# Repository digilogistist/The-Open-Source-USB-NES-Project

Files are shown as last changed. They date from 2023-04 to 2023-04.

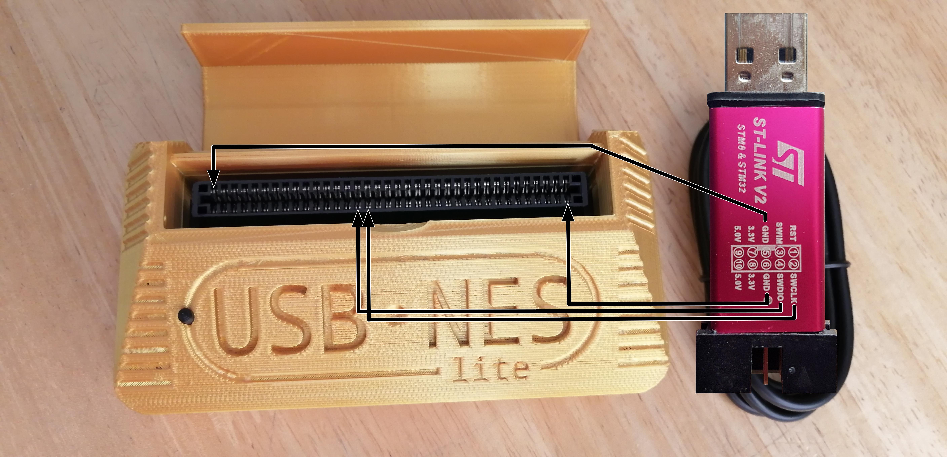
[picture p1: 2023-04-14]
USB-NES-SWD_pinout.jpg

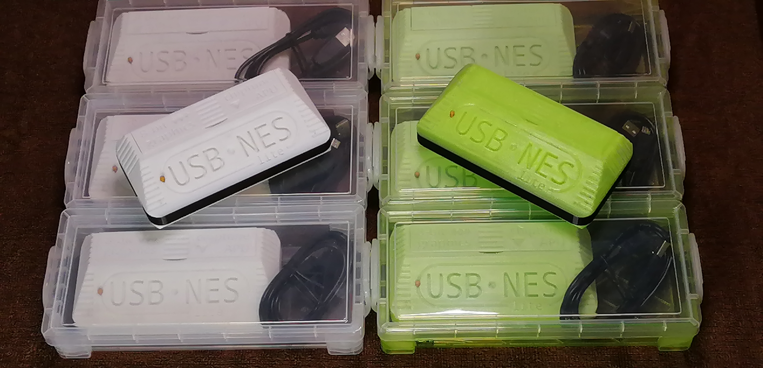
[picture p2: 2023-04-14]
gallery/IMG_20230210_211953.jpg

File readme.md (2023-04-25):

# USB-NES Lite Project Public Release

Brad Taylor  
BTTD Group  
04/05/2023  
https://usbnes.com  

### This is the complete USB-NES Lite 0.08/0.79 production unit engineering archive, containing:

- Source code
- Firmware binaries (composite and discrete)
- PCB engineering files (USB-NES, NES-BACKUP and new NES-FASTGFX)
- Serial wire debug wiring diagram
- Technical documentations
- Quick setup guide print-out
- DIY kit guide print-out (manufacturing instructions)
- Owner's manual PDF
- 3D case models
- Manufacturing BOMs and part source links
- Photo gallery

## Firmware Binaries

Inside the USB-NES is an STM32F103C8 microcontroller running at 72 MHz, which usually includes a very cozy 64 K Bytes of on-board flash memory.  Sometimes as a bonus though, the "Blue Pill" comes with double that amount of storage (and possibly even all the time).  While these differences are normally considered a toss-up on a few innocent chance purchases, the 128 KB flash types (aka incognito 'F103CB ones) are more commonly seen with marketplace Blue Pill system boards at slightly higher price points.

Nowadays, the Blue Pills are not as cheap, available, nor as powerful as newer mini system board offerings on the market, but the first generation blue pills with the through-hole mounted micro-USB port and low-profile reset push button switches are the absolute best types you can still get your hands on, if you're lucky.

Moreover, the main functional USB-NES firmware uses only the first 64 KB of flash, where as units with 128 KB would include a DEMO.NES graphics demonstration ROM that would fit in the bonus 64 KB of flash as additional superfluous brand marketing.  The firmware checks for the classic iNES signature where the DEMO.NES file is allocated on the flash to determine if the file should be created in the USB-NES file system.  Therefore, the DEMO.NES binary allocated there can technically be any defacto .NES image that can fit within the high 64 KB flash of a lucky 128 KB Blue Pill sample.  

|Micro Type  |Flash Location|Size  |Composite Binary Source |
|:---|---:|-----:|:---|
|STM32F103C8 |0x 0800 0000  | 64 KB|/USB-NES_Lite_0.08-0.79_64K.bin |
|STM32F103CB~|0x 0800 0000  |128 KB|/USB-NES_Lite_0.08-0.79_128K.bin|

~ may also be labelled as a "lucky" 'F103C8 model.  

|Flash section |Flash Location|Size |Discrete Binary Location |
|:---|---:|----:|:---|
|Boot Block @|0x 0800 0000  | 4 KB|/firmware/boot_block/boot_block.bin |
|Kernel ~$|0x 0800 1000  |28 KB|/firmware/kernel/Debug/kernel.bin |
|Application ^$|0x 0800 8000  |26 KB|/firmware/application/Debug/application.bin|
|SETTINGS.TXT %|0x 0800 E800  | 1 KB| |
|BCMTABLE.BIN  |0x 0800 EC00  | 1 KB|/firmware/BCMTABLE.BIN |
|OVERRIDE.BIN  |0x 0800 F000  | 4 KB|/firmware/OVERRIDE.BIN |
|DEMO.NES &|0x 0801 0000  |64 KB|/firmware/DEMO.BIN |

~ Uses lower 10 KB of system RAM  
^ Uses upper 10 KB of system RAM  
$ Compiled using Atollic TruStudio (see ./BUILD.BAT for console log)  
% This data is auto-generated by the application firmware  
& DEMO.NES is disabled in SETTINGS.TXT by default  
@ Assembled and output to binary using windy script /firmware/boot_block/BUILD.BAT  

### Flashing the discrete binaries to USB-NES
1. Acquire an ST-LINK Serial Wire Debug programming tool; they are cheap + easy to get.
2. Install the ST-LINK programming utility software.
3. Refer to the /USB-NES-SWD_pinout.jpg for connecting the ST-LINK to USB-NES via SWD.
4. Be sure the USB-NES has its USB port powered when connecting via SWD.
5. Hold in the reset button on USB-NES for a couple of seconds or so, while using the ST-LINK utility to connect to the STM32F103 micro via SWD interface.
6. Deactivate the readout protection on the STM32F103 by unchecking it in the option switches.  Please note this will completely erase the existing contents of the USB-NES firmware.  If the readout protection is not active, you should instead erase the entire contents of the chip by using the utility's Erase command.
7. Load the binary files into the ST-LINK utility~, and program them to the aforementioned corresponding locations in flash memory.  The five critical binaries to flash to USB-NES are the Boot Block, Kernel, Application, BCMTABLE.BIN, and OVERRIDE.BIN.  SETTINGS.TXT is auto-generated by the application, and DEMO.NES is entirely optional (for 128 KB units only).

~ Alternately, the ST-LINK utility command line interface may also be used to flash all five critical binaries automatically; please see /FLASHBALL.BAT for a windy example.

## Source Code

The Kernel and Application projects offered here are built with STM32cubeMX, using the USB FS and mass storage class middlewares provided by ST Microelectronics, which is copywritten code.  Therefore, their source code is provided here strictly under the "fair use" doctrine; no infringement is implied nor intended in its parallel inclusion with this public-domain USB-NES preservation project and related functional source code files.

This default USB layer uses almost all the flash space in the kernel, but probably can be optimized to use less.  Moreover, the STM32cubeMX does not allow the implementation of a USB composite device (such as MSC + HID) on this particular STM32 micro; this is why USB-NES Lite never got NES gamepad socket add-ons over its trial run.  Many on-and-off attempts were made to hack together the two separate STM32 USB functions with no success; it is not clear to me at the time of this writing if the STM32F103C8 has enough flash or RAM resources to employ a USB MSC + HID composite device within the confines of the kernel binary.

The main functional USB-NES source code provided here is located as follows:

|Source type|Language  |Size  |Location |
|:---|:---|-----:|:---|
|Boot Block |ARM M3 ASM| 13745|/firmware/boot_block/boot_block.s |
|Kernel |C | 25177|/firmware/kernel/Src/usbd_storage_if.c|
|Application|C |120352|/firmware/application/Src/main.c |

## PCB Files

Both USB-NES-02 and NES-BACKUP-02 are electrically identical products, and differ only with the Blue Pill/USB port orientation (side vs. back) to their respective PCBs.

The NES-BACKUP-02 PCB predates USB-NES-02, and does not have a nice shell design like for USB-NES Lite.  Note the only feature of this PCB is the 6-pin header that connects to the NES cartridge CIC pins, for easy AVR CIclone boardset programming.  Only 11 NES-BACKUP-01 units are currently known to exist.  Note there is no corner mounting holes, nor is there a footprint for the necessary electrolytic capacitor in this design, which are bugs that need addressing.  The -02 revision fixes a footprint pinout bug present on the -01 models, involving the orientation of the power MOSFET component.

USB-NES-02 is a better follow-up PCB to the aforementioned design, that adds in an experimental mini phone plug for theoretical expansion audio access, and leaves room in the front for further possible expansions like NES gamepad ports and such.  At least 100 USB-NES-01 PCB assemblies are known to exist, and many of these have been assembled into complete USB-NES Lite consumer units.  Note there is no footprint for the necessary electrolytic capacitor in this design, but it is possible to piggy-back solder it onto existing points on the PCB assembly (see /cap_add/ for pix).  A 1.6 mm PCB thickness is strongly recommended for manufacturing USB-NES-02.  All USB-NES firmware binaries mentioned in this document are intended for USB-NES-02.

USB-NES-04 is an enhanced version of the previous design that adds four controller ports to the USB-NES.  There is no firmware that exists yet to take advantage of the enhancements in this hardware design.  Moreover, no PCBs nor related shell designs have yet been manufactured for this either.  More info here:  
https://youtu.be/dRpi10Yrjks

NES-FASTGFX-01 is a completely original concept NES cart mapper (1.2 mm thick) PCB design made for new NES game development.  A complete manufacturing BOM + working (as of 04-13-2023) parts source list for NES-FASTGFX-01 can be found in "/PCB (NES-FASTGFX-01)/BOM-FASTGFX.ods"

### NES-FASTGFX-01 Specs
- 512 K byte PRG flash (SST39SF040)
- 32 K byte PRG-RAM
- 512 K byte CHR-RAM
- 32768 playfield tiles (@ PPU $0000-$0FFF)
- 4 PPU mirroring modes
- 16-bit VBLANK time stamp counter
- 128 sprite banks (@ PPU $1000-$1FFF)
- HI name table located in first 2 KB of CHR-RAM
- 4-CPU clock cycle CHR-RAM byte filling @ PPU $2000-$3EFF~
- ATMEL ATtiny13A CIClone twin footprint (through-hole & SMT)

~ CPU writes to PPU data I/O register $2xx7/$3xx7, will write the encoded 8-bit xx value to the CHR-RAM in one single STA/STX/STY abs. 6502 instruction.  In this case, writes to PPU $2000-$2FFF memory will fill the HI name tables with the xx value (and internal 2 KB LO NT as per usual CPU data), while writes to PPU $3000-$3EFF will write xx to the selected CHR-RAM sprite bank (meanwhile disabling the LO NT).  The CHR-RAM may also be disabled during name table fills, when updating only the LO NT is desired.   Moreover, the CHR-RAM may also be bi-directionally accessed via the traditional CPU $2007 data I/O port @ PPU $1000-$1FFF memory, swapping in the selected 4 KB sprite bank there as well.  PPU bank $0000-$0FFF is only used for playfield rendering; it can just be ignored otherwise.

The most notable feature of this mapper is the expansion of the original 8-bit name table tile codes to 15-bits; this is made possible by using a private graphics data bus in the cartridge for handling the NT HI business during a NT fetch phase.  Moreover, the NT fetch phase is identified as a read cycle from PPU $2000-$3FFF that follows a read from PPU $0000-$1FFF; this corresponds to how the PPU fetches CHR memory during on-screen playfield rendering.  The NT HI byte is then fetched from the first 2KB of CHR-RAM (using the identical mirroring scheme the NES internal 2K VRAM is configured for), and is stored in a register.  The register is then used as the basis for the 4KB bank selection for pattern graphics access @ PPU $0000-$0FFF, which is where the PPU should be normally configured to allocate the 4KB playfield graphics bank.

The VBLANK time stamp counter is reset from any reads from the PPU, so once screen rendering is done, this counter will start to count up every CPU clock.  Consequently, the 16-bit value read here can indicate how far the PPU is in VBLANK or the frame render period, relative to the CPU NMI event (or thereabouts).  If your VBLANK code runs past the 20-scanline (NTSC) limit, the time stamp counter can be used as the basis for forming the correct PPU scroll programming values, based on how many scanlines the render has advanced into the visible frame.  Reading the LO byte of the time stamp count register latches the next LO and HI 8-bit time stamp count samples to be read back.  Therefore, it is possible to only just read the LO TSC register when measuring CPU clock counts of less than 256 clocks.

When using FASTGFX for NES game development, writing to PPU memory is up to 50% faster, and VBLANK code time may be extended dynamically past the on-screen cutoff point, all while having access to a serious amount of graphical tiles for use with both backgrounds and sprites.

### Flash Cart Story
NES-FASTGFX-01 is the answer to a previous programmable NES cart production attempt I made back in 2018: "NES-RED-PILL-02". This older design was more complicated due to the presence of both CHR-RAM and CHR-flash, where the PPU architecture is split into separate sections for sprites (RAM) and playfield tiles (flash/RAM).  The idea was to have 512 KB of CHR-flash for background tiles, and 32 KB CHR-RAM for sprites + BG, but the hardware required to implement the 16-bit background tile index code extensions ended up making programming the CHR-flash chip a complex nightmare.

This was also my first attempt implementing 5-volt flash chips into a new NES cart design.  One critical detail about using flash chips for PRG memory versus SRAM is the requirement of an inverted read/write line for the /OE input on the chip, which would normally just be tied to ground for a typical SRAM implementation.

My long-term plan was to develop game software for the NES using these cart boards, while using NES-BACKUP/USB-NES as the main flashing/programming tool, providing an easy-to-use drag + drop user interface.  These boards have a lot of SMD parts on them, so I got ten of them manufactured and populated professionally, which also made this cart production really expensive.

Subsequently however, once I had built NES-BACKUP and started testing out the NES-RED-PILL boards, I found out I made some fatal design mistakes on the boards.  Most notably, I discovered that both CHR and PRG flash chips could not be programmed efficiently or even at all, without reworking the boards and adding another chip!  After eventually reworking one board, I did manage to get the PRG + CHR flashing to work with USB-NES, but when programming the CHR-flash there was always 4KB in the last bank on the chip that would not flash correctly.  I couldn't figure out what the source of the CHR-flash corruption was, and lost my nerve.  From there on (late 2019), I focused on developing the USB-NES firmware, since I was at a loss with my game boards.

Then three years later, I reworked a second NES-RED-PILL board to discover that the CHR-flash on the first board was actually fried.  Apparently, all the initial testing I was doing on these boards before reworking them was enough to cause the CHR-flash chip on one board to partially self-destruct, and cause it to always fail a full flash memory programming test.  But now, the second reworked board was flashing perfectly using USB-NES!  So now I know what I did wrong, and how to do it right this time.

I took everything I learned from that first costly and disappointing NES-RED-PILL production disaster, trimmed the fat and tweaked the ideas, and made NES-FASTGFX: a state-of-the-art, open-source, graphics expansion NES development cartridge boardset PCB design, that adds powerful extensions to the NES architecture with a simplified programming environment, using a handful of easy-to-source boardset parts.

USB-NES support for NES-FASTGFX boardset development with full drag + drop PRG-flashing is speculated down the road, using existing methods in the USB-NES source code that have been 100% tested and confirmed working on reworked NES-RED-PILL-02 flash boards.  More info on the NES-RED-PILL can be seen here:

https://youtu.be/C34mVn180Tk  
https://youtu.be/JX10NZo6VX4

## USB-NES Lite BOM

/BOM-final_USB-NES_Lite_2021.ods

This bill of materials includes everything to make a production USB-NES Lite system, with a working (as of 04-13-2023) part source list.

The 3D models are typically printed via 1.75/0.4 mm filament/nozzle 3D printer with 5% infill, 0.2 mm layers, and 1.2 mm top/bottom thickness.

The PCB files were made with Kicad.

Do not assemble before reading the manufacturing instructions.

## Manufacturing Instructions

The step-by-step assembly guide for building USB-NES Lite is contained in:  
/USB-NES DIY KIT (p.1).pdf  
/USB-NES DIY KIT (p.2).pdf  
https://usbnes.com/usb-nes-lite-diy-kit/  

The companion video can be found here (doesn't cover adding the capacitor):  
https://youtu.be/VL_1Z1ONgns  

The capacitor install guide here:  
/cap_add/  
https://usbnes.com/power-system-upgrade/

## Thank-Yous

All the USB-NES Lite project supporters  
The entire NES emulation dev scene  
Generational Gamer  
Paul Belanger  
Thor Robinson  
Troy Denton  
Henry Hoy  
Wolf  
Loopy  
Disch  
Dwedit  
Blarrg  
nocash  
Tepples  
Kevtris  
Bootgod  
Bregalad  
Bananmos  
Tokumaru  
Lidnariq  
Ulfalizer  
Rainwarrior  
infiniteneslives  
beannaich  
Quietust  
Memblers  
jeffqchen  
NEScartDB  
NESDEV wiki  
Eugene's blog  
ST Microelectronics  
Nintendo of America, Inc. (and NCL of Japan, too)  
And of course, the reader  

## License

Copywritten works, such as technical manuals and source code included in this repository are for educational and preservational "fair use" purposes only.  No copyright infringement is implied, solicited nor intended with the inclusion of these copywritten works for the Open-Source USB-NES Project.

The rest of the work in this archive, including any BTTD Group or Brad Taylor properties, is licensed under a Creative Commons Attribution-ShareAlike 4.0 International License.

http://creativecommons.org/licenses/by-sa/4.0/

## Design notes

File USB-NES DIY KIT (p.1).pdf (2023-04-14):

USB-NES Do-It-Yourself Kit Assembly Guide
Brad Taylor
OCT 17 2022

Please see our DIY companion video and documentation on our website for more info: https://usbnes.com/usb-nes-lite-diy-kit/

1. What you’ll need:
* USB-NES Lite parts kit (thank-you for your purchase)
* USB-NES 3D print model
* Filament 3D printer
* Fine-tipped soldering iron + station + solder
* Solder wick (optional; for removing solder bridges and excess solder) * “3rd Hand” PCB holder
* Magnifying glass (optional; for inspecting solder joints)
* Flat-tipped or electronics’ tweezers
* Lineman’s pliers / needle-nose or similar type
* #1 Phillips screwdriver
* Utility knife
* Flush cutters (optional)
* Intermittent soldering skills
* Patience and persistence (estimated 1 hour assembly time)
2. Open and Examine the USB-NES assembly kit:
1x Protective jewel case
1x STM32 barebones system “blue pill” board (preprogrammed with current USB-NES firmware) 1x 40-pin single-inline header
1x 4-pin single-inline header
1x 6-pin dual-inline header
1x thin jumper wire
1x Printed circuit board “USB-NES-01” 1x 72-pin NES cart connector
1x surface-mount 10k-ohm resistor
1x surface-mount P-channel power mosfet 1x surface-mount level shifter
1x 3ft. Micro-USB cord
4x #4-40 x 1″ machine screws
2x #4-40 x 11/16″ machine screws
1x 560 uF electrolytic capacitor
3. Prep the pin headers:
* Break the 40-pin header into 2 equal sections of 20 pins.
* Use pliers to straighten the 4-pin header
* Use pliers again to slide the 4-pin header spacer down to be equal to that of the other 20 pin ones. * Remove and discard the 2 yellow jumpers from the 6-pin header.
4. Prep the blue pill board (Very Important!):
* Remove and discard R4 from the board with the soldering iron by heating both
sides of the surface mount resistor and pushing it away from the other components. * Tin one end of the thin jumper wire that came with the kit.
* Use the thin jumper wire to bridge R4. Cut the excess wire off neatly with a knife. * (optional) Apply some extra solder on the 4 mounting holes
for the micro-USB header to improve structural integrity.
5. Prep the USB-NES board with the surface mount parts:
* Place a small amount of solder on a single pad within the part’s footprint.
* Use the tweezers to place the part on top the board oriented with the footprint; hold it steady. * Heat the soldered pad with the soldering iron while pressing the part against
the board until the lead from the part makes a good bond with the solder.
* Solder the rest of the leads of the part to the pads.
* Repeat this process for all 3 surface mount parts.
* Use a magnifying glass to inspect for good solder joints and identify any solder bridges on the surface mount parts (especially on the 5-lead level shifter chip). * Use solder wick to clean up any bridges or excess solder.
6. Stuff the pin headers into the USB-NES board:
* Stuff the 2x 20-pin and 6-pin headers long-side-up into
the topside through-holes of the blue pill footprint.
* Make sure the header spacers are flush with the surface of the board. * Repeat all these same steps for the 4-pin header afterwards.
* Use pliers or other means when inserting tight headers.

<continued on back...>

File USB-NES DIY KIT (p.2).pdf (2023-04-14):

<PAGE 2 | USB-NES DIY KIT Assembly Guide>
7. Solder the blue pill to the pin headers on the USB-NES board:
* Place the blue pill ontop the headers with the USB port
facing upwards, and press it flat against the header spacers.
* Solder all the pin header joints to the blue pill.
* Flip the board around and apply solder in the 4 corners of the blue pill footprint. Keep the blue pill as flat as possible against the mainboard.
* Solder the rest of the pins to the mainboard.
8. Solder the electrolytic capacitor onto USB-NES:
* Cut the positive lead (opposite the minus side) on the capacitor to 1/2″ (13 cm).
* Bend the capacitor leads apart a small amount.
* Tin the ends of the capacitor leads with solder.
* Add an excess amount of solder to the GND pin on the blue pill (next to the DCLK pin). * Add an excess amount of solder to the source lead on the power MOSFET
connected to the thick 5 volt rail running to the 5V pin on the blue pill.
* Solder the negative lead of the capacitor to the GND pin on the blue pill.
Leave 1 mm spacing between the negative lead and the blue pill PCB.
* Solder the positive lead of the capacitor to the source lead on the power MOSFET. * Position the cap so it can rest flush against the USB-NES circuit board.
9. Solder the 72-pin cart connector to the USB-NES board:
* Carefully line up the pins on the cart connector to the through-hole
footprint on the top of the board and push it in flush with the board.
* Flip the board over and solder the pins on all 4 corners of the connector to the board while pinching the connector flush against the board from the other side. * Solder the rest of the connector pins to the board.
10. Test the USB-NES:
* Follow the included "Quick Start Guide" paper instructions.
11. Download and print the USB-NES Lite 3D models:
* Download the 3D model print package (found in the USB-NES section) from our website: https://usbnes.com/wp-content/uploads/2021/08/08-20-2021-USB-NES-lite-Case-Full-Print.7z * There are 5 models in the package. An extra, alternate bottom model that has no branding is also provided to reduce print time by ~1 hour.
* Use your favourite slicer to organize the models as you see fit for your filament printer. * Print all 5 models: top, middle, bottom, dust cover hinge, reset button.
* Use a 5% infill for all prints.
* Set top/bottom walls to 1.2 mm.
* For PLA, use 220°C to get the best results on fine details like lettering on the first print layer. * Use a 52° – 55°C print bed temperature to minimize print warping and curling.
A confined printing enclosure is recommended for best results.
* Do not print supports.
12. Assemble the USB-NES case:
* Use your knife to cut away any excess plastic around the hinges of the dust cover. * Cut away any debris on the sides of the interlocking parts.
* Wipe any fine strings away on the PLA print with a clean cloth.
* Carefully pop the the dust cover door into the bottom piece by
positioning the door hinges on top the back rockers and pressing in.
* Adjust the door hinge so its angle is flush with the bottom piece.
* Place the reset button through the hole of the top piece print from the bottom.
* Pop the fully-assembled USB-NES board into the middle piece print.
* Pop the bottom of the middle assembly into the bottom assembly. Watch the bottom posts of the middle assembly align with the hole cutaway for the back rockers on the bottom piece. * Sandwich the top and bottom assemblies together.
* Use the 4 x 1″ screws to fasten the 3 layers together using the
holes closest to the NES cart slot. Do not over-torque the screws.
* Use the 2 x 11/16″ screws to fasten the layers together using the
holes closest to the front of the unit. Do not over-torque the screws. Do not over-thread these screws or they may pop out the top of the unit.

And that’s it!

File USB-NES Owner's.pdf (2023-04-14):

How to use USB-NES Lite
Brad Taylor
BTTD Group

03/13/2019
07/16/2021
05/06/2022

Hardware you will need
- A computer, tablet or other smart device that can access USB mass storage devices
- A micro USB cable for interfacing USB-NES to a smart device
- A USB-NES unit
- A NES game cart
- One or more USB game pads

Software you will need
- NES Emulator application installed locally to smart device.
These links will take you directly to a few emulator download pages. Here, you can choose the app version for your platform.
Any of these emulators can work if it supports your smart platform.
It is recommended to consult the emulator's user's guide after install.
FCEUX | http://www.fceux.com/web/download.html
Mesen | https://www.mesen.ca/#Downloads
Nestopia UE | http://0ldsk00l.ca/nestopia/
Nintendulator | https://www.qmtpro.com/~nes/nintendulator/#downloads
RETRO ARCH | https://www.retroarch.com/?page=platforms

RETRO ARCH is not an emulator but rather a front-end (similar to RetroPie) that makes it easy to manage collections of ROMs and emulators for hundreds of systems. The application is designed to work on touch-screen smart devices, and has very good platform support to date. A setup guide is mentioned later.

Quick RETRO ARCH (RA) setup
- Download and install RA on your device.
- Connect your USB game pad to your device.
- Connect USB-NES to your device.
- Run RA. The main menu should appear.
- Navigate into "Load Core -> Download a Core".
- Browse down to where you'll find a "Nintendo - NES / Famicom" section.
- Select an NES emulator; it will download and install automatically.
- Back in the main menu, navigate to "Load Content" and then to the USB-NES drive.
- Select "ROM.NES", and then select the NES emulator to run the ROM on.
- USB game pads should work immediately with no additional configuration necessary.

Firmware you need
Visit https://usbnes.com/usb-nes-firmware-upgrades-compatibility/ to upgrade your unit.
- USB-NES_Lite | version 0.71 (or later)
- USB-NES kernel | version 0.08

How to connect USB-NES
1. Plug your NES game cart into USB-NES with the label facing towards the front of the unit.
2. Plug your USB-NES into a smart device using a micro-USB cable. The red light on USB-NES will light; this is the USB power indicator.
3. Wait for your smart device to recognize USB-NES as attached mass storage media. When this happens, you will see a green light on the unit go on for a second; this is USB-NES trying to detect the type of NES cart (your OS may also pop up a USB-NES drive folder on the screen after this).

What's on the USB-NES drive?
ROM.NES | The game cart ROM file in .NES format
ROM.SAV | The game save file (games with save RAM)
REPORT.TXT | auto-detected information about ROM.NES
SETTINGS.TXT | USB-NES system enable controls and timings
VERSION.TXT | Reports the firmware name and version
README.TXT | Link to USB-NES website
SECURITY.BIN | Authentication file for firmware upgrades
FIRMWARE.BIN | USB firmware upgrade file (write-only)

New USB-NES files
DETECT.TXT | Autodetect the cartridge and display REPORT.TXT data
OVERRIDE.TXT | Create and edit text override patches to read and auto-detect more games
OVERRIDE.BIN | A compressed binary mirror of OVERRIDE.TXT
PRG.BIN | abstract file for PRG-ROM flash (write-only)
CHR.BIN | abstract file for CHR-ROM flash (write-only)

Bus conflict mapper test system files -------------------------------------
BCMTABLE.BIN | Bus conflict mapper test descriptor table
BCMSCORE.BIN | BCM test score results
ROOT_TBL.BIN | BCM root bankswitch table
DATA_TBL.BIN | BCM value bankswitch table

How to run the ROM
1. Before starting the game, ROM.SAV may have to be copied out to your emulator's SAV file folder to play saved games properly. The ROM.SAV may also be written back to the cart.
2. ROM.NES can be dragged & dropped onto your NES emulator app to run the cart. You can also use the "Open ROM" file menu dialog to browse to the USB-NES drive and open the ROM.NES file there. Running from command line is also possible.
3. You will have to configure your emulator's input settings to map your keyboard or game pad to the NES 8-button layout. Most emulators have a similar way of doing this; it is recommended to consult the user's guide to find the specific way your emulator maps NES controller buttons.

Edit SETTINGS.TXT
The settings file is the main way to configure USB-NES. It allows CPU/PPU bus timings to be adjusted, the enabling or disabling of many system files and internal auto-detection tests, and the unit may be configured to operate in a manual override mode where USB-NES behaviour can be fixed to implement a specific mapper abstract.

CPU_R, CPU_W, PPU_R, PPU_W
bus timing parameters in nanoseconds between 0-1000.
A setting of 0 for all parameters yields the fastest cart reading. (removed since firmware version 0.75)

powerup_warmup_ms
A delay in milliseconds from cart power activation to
first ROM read access.

idle_powerdown_ms
wait time from last ROM read access to switching the cart power off.

batt_powerdown_ms
power down wait time in milliseconds before reactivating cartridge power when trying to detect save RAM.

PD_discharge_enable
discharge the cartridge in the middle of the batt_powerdown event to aid in the save RAM detection. It is recommended to keep this parameter disabled = 0.

battery_test_enable
enable the detection of save RAM by turning cart power off for batt_powerdown_ms, and then back on. This occurs when WRAM is detected in the cartridge.
This is usually enabled =1.

ROM.W_bus_disable
Disables USB-NES write cycles to PRG addresses $8000 - $FFFF. This setting is mostly a curiousity for troubleshooting
bus conflict mapper test identification mistakes.

OVERRIDE.BIN_enable, README.TXT_enable, DETECT.TXT_enable, OVERRIDE.TXT_enable, REPORT.TXT_enable
Creates the corresponding files in the USB-NES root when =1.

BCMTABLE.BIN_enable
Access the bus conflict mapper test descriptor system table. This file must be present on USB-NES for any of the bus conflict boardsets to be auto-detected by USB-NES.
Note this file may be edited to provide customization for the user.

BCMTABLE_reporting
Creates the BCMSCORE.BIN, ROOT_TBL.BIN & DATA_TBL.BIN files. These files are used as a diagnosis system for determining why mappers with bus conflicts sometimes can't be identified correctly.

ASIC_map_testing_on
Enables all the internal ASIC mapper tests.
These are all mappers free of bus conflicts when writing to the $8000 - $FFFF area.

alt_buscon_tests_on
Enables testing for mappers that have bus conflicts but have their bankswitch registers outside the contentious PRG-ROM memory area.

conflict_testing_on
Enables testing for mappers as per the BCMTABLE.BIN.
Up to 32 BCM-type mappers can be described in this table. Note this table needs to be copied onto USB-NES after any kernel upgrades.

16_KB_PRG-ROM_test
If the internal tests indicate the game has a 32 KB PRG-ROM, this test is carried out to determine if the ROM is just doubled-up or not.

override_testing_on
Enables the testing of mapper override abstracts in OVERRIDE.TXT that have any TEST sequence scripts.

default_map_index
Selects a default mapper override script to use for USB-NES when the unit detects no cartridge in the slot.

NES_2.0___enable
Can force creation of the NES 2.0 flags in the header if =1. Note that games that use mapper numbers greater than 255 will automatically be set to NES 2.0.

By setting this =2 to =9 you can enter the USB-NES into manual override mode where all autodetection is disabled, even when accessing DETECT.TXT. The index value here corresponds to the first 8 valid mapper override scripts present in OVERRIDE.TXT, plus the default_map_index value.

Stuff
- Most the new features, such as the OVERRIDE.TXT scripting language is documented on usbnes.com.
- For best results, always use NES carts that have clean cart edge fingers. There are many guides on the internet about how to clean NES game carts.
- Do not pull carts in and out of USB-NES when the green light is on. This light indicates when the cartridge is powered up; typically the first time the unit is plugged in to USB, and the first time the emulator reads the ROM.NES file.
It is safe to change carts when the green light is off.
- There are 3 ways to change the NES media on USB-NES. The best and preferred way is simply to read out the DETECT.TXT file, and the host will wait until USB-NES probes the cartridge slot again to make a report. You may also press the reset button on USB-NES but this doesn't work as a fool-proof solution on every platform. The last is a simple USB unplug-replug; this re-initializes USB-NES and configures it for the new cart.
- Multiple USB-NES units may be connected to a computer at one time. It is recommended to use a powered USB hub for setting up this type of configuration.
- USB-NES has support for many cart types, but not all NES games can be autodetected with USB-NES. However USB-NES's autodetection system can be augmented to add support for more games at the user level with OVERRIDE.TXT.

- When a game doesn't work, try re-inserting the cart and USB cable 2 or 3 times.
- USB-NES may not work on smart devices lacking a proper type-A USB connector,
or lacking USB on-the-go (OTG) support.
- To default the SETTINGS.TXT file you can delete one or all lines in the file, and then save it (make sure the file size is > 0 or the save won't work). The settings will be regenerated with the default parameters with the next autodetection.
- Future USB upgrades to the USB-NES firmware are possible. Visit: https://usbnes.com/usb-nes-firmware-upgrades-compatibility/

Anti-piracy terms
BTTD Group does not endorse piracy. The digital ROM image of a NES game cart's copyrighted work (ROM.NES) does not have to be copied off the virtual USB-NES drive in order for an NES emulator to run the ROM.NES file.

Commercial NES game cartridges purchased by consumers are allowed to be backed up to a digital copy for personal archival purposes. However, the distribution of copyrighted works, such as from the NES era, is still illegal and infringes the law.

It is therefore up to the user to determine whether their use of USB-NES infringes copyright laws or not. BTTD Group shall be in no way held accountable for the actions and subsequent legal consequences of users who use USB-NES to intentionally promote piracy and/or violate copyright laws.

Limited liability
BTTD Group is in no way responsible for any losses, damages or illness caused by the user's use of USB-NES, directly or indirectly, intentional or not. The user agrees to these terms and the anti-piracy terms by reading this README.TXT file, and using the USB-NES.

Copyright (C) 2018-2021 The Big Time Technology Development Group. All rights reserved.

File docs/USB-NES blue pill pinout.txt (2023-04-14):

blue pill <---> NES interface
Note CPU and PPU data and address lines are tied together

pa00	 o	A8
pa01	 o	A9
pa02	 o	A10
pa03	 o	A11
pa04	 o	A12
pa05	 o	A13
pa06	 o	A14 (PPU /A13)
pa07	 o	/ROMSEL
pa08	 o	M2
pa09	 o	CPU R/W
pa10	i	IRQ
pa11
pa12
pa13	i	NT.A10
pa14	 o	PPU /RD
pa15	 o	PPU /WR

pb00	 o	A0
pb01	 o	A1
pb02	 o	A2
pb03	 o	A3
pb04	 o	A4
pb05	 o	A5
pb06	 o	A6
pb07	 o	A7
pb08	io	D0
pb09	io	D1
pb10	io	D2
pb11	io	D3
pb12	io	D4
pb13	io	D5
pb14	io	D6
pb15	io	D7

pc13	 o	/POWER

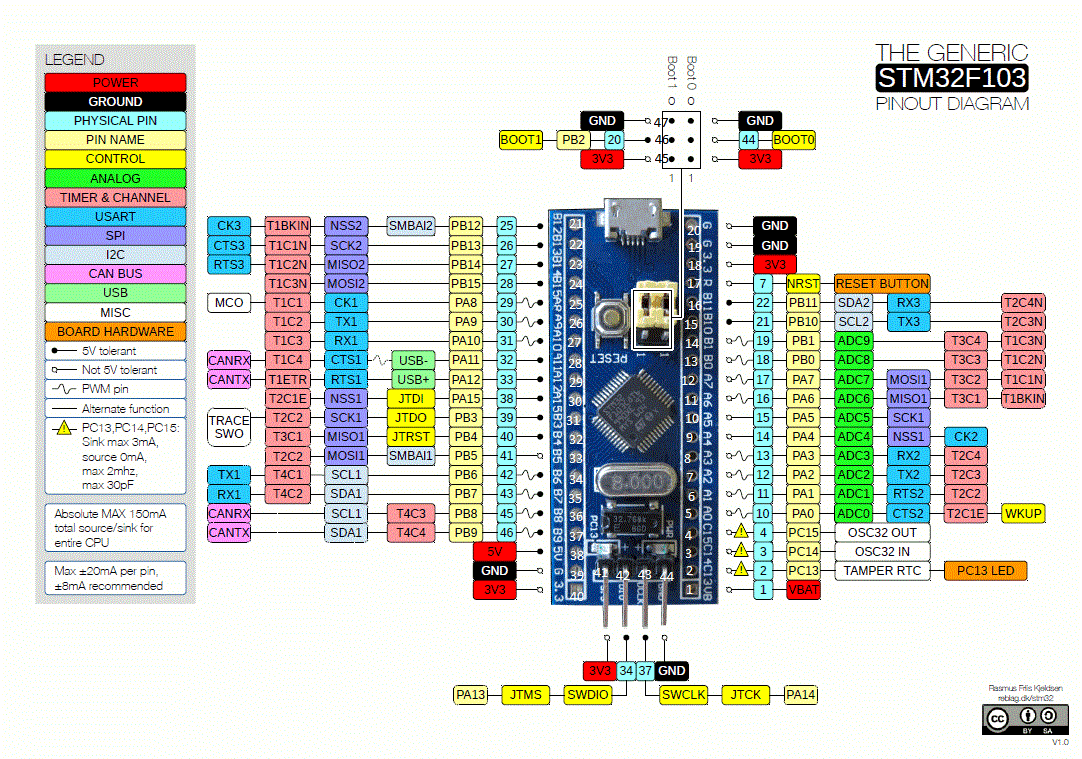
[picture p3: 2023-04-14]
docs/Bluepillpinout.gif

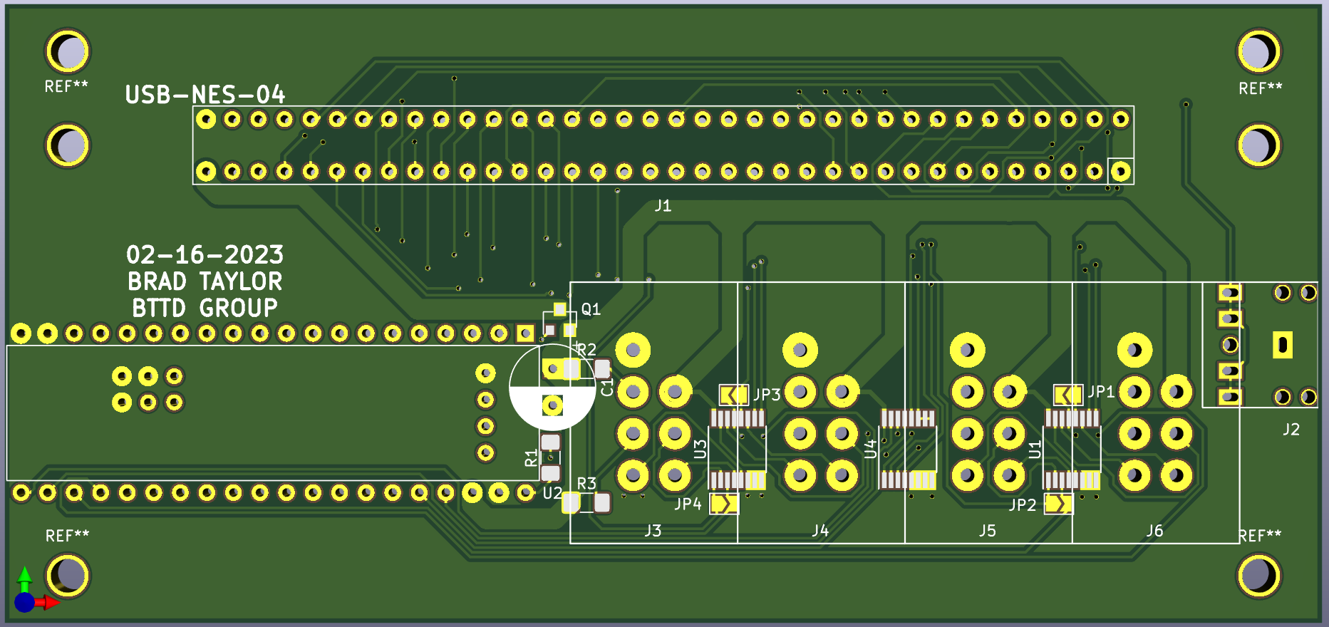
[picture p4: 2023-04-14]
gallery/Screenshot_2023-04-13_22-25-10.png

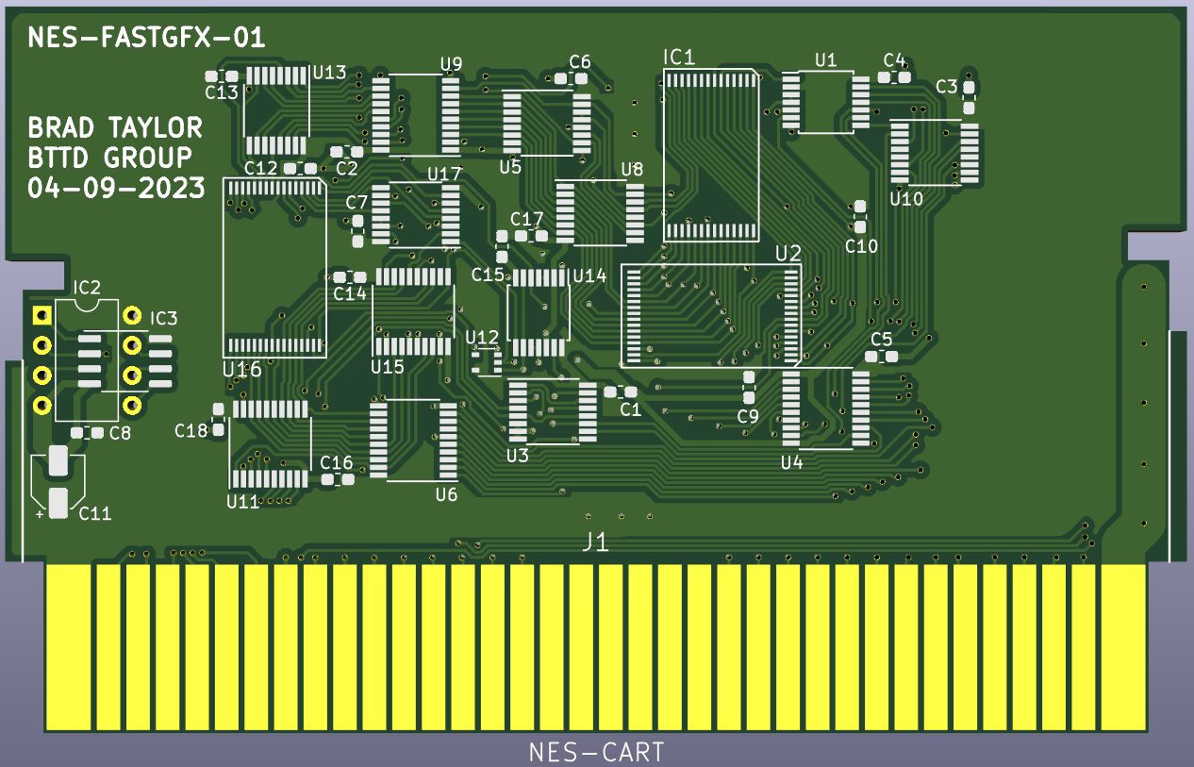
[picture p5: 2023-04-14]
gallery/Screenshot_2023-04-13_22-22-10.png

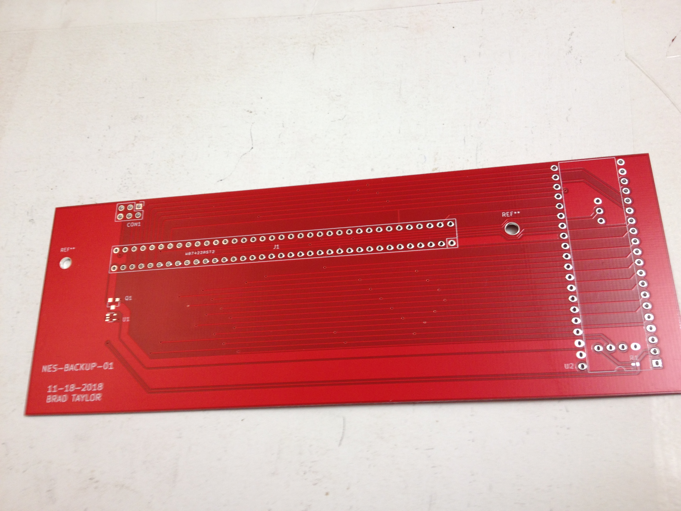
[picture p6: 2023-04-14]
gallery/NES-BACKUP front (unpop).JPG

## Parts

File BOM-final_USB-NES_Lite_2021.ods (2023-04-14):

part description | part # | quantity | resource location
72-pin cartridge connector |  | 1 | https://www.aliexpress.com/item/32865905959.html
 |  |  | https://www.aliexpress.com/item/1005004794321751.html
P-channel power MOSFET | TSM500P02CX RFG | 1 | https://www.digikey.com/en/products/detail/taiwan-semiconductor-corporation/TSM500P02CX-RFG/7360423
Single tristate line buffer | 74AHCT1G125W5-7 | 1 | https://www.digikey.com/en/products/detail/diodes-incorporated/74AHCT1G125W5-7/2711990
10K Ohm 1206 chip resistor | CRCW120610K0JNEAC | 1 | https://www.digikey.com/en/products/detail/vishay-dale/CRCW120610K0JNEAC/7928623
560 micro Farad radial electrolytic capacitor | 10AX560MEFC8X9 | 1 | https://www.digikey.com/en/products/detail/rubycon/10AX560MEFC8X9/4842240
STM32F103 "Blue Pill" barebones system board | OG_BLUE_PILL | 1 | https://www.aliexpress.com/item/1005004525786963.html
Machine screw pan head Phillips Stainless Steel 18-8, #4-40 x 1” | 1ZB45 | 4 | https://www.grainger.com/product/GRAINGER-APPROVED-Machine-Screw-4-40-Thread-1ZB45
Machine screw pan head Phillips Stainless Steel 18-8, #4-40 x 11/16” | 1ZB42 | 2 | https://www.grainger.com/product/GRAINGER-APPROVED-Machine-Screw-4-40-Thread-1ZB42
Advantus Super Stacker pencil box, clear | #10608900 | 1 | https://www.michaels.com/product/clear-stacking-pencil-box-by-simply-tidy-10608900
20-pin dual-inline header |  | 2 | Comes with Blue Pill
6-pin dual-inline header | ! | 1 | Comes with Blue Pill
4-pin mono-inline header | ! | 1 | Comes with Blue Pill
USB-NES-02 printed circuit board | % | 1 | /PCB (USB-NES-02)/USB-NES_v02/
DIY kit step-by-step guide page 1 printable | * | 1 | /USB-NES DIY KIT (p.1).pdf
DIY kit step-by-step guide page 2 printable | * | 1 | /USB-NES DIY KIT (p.2).pdf
Quick setup guide 1-page printable | * | 1 | /USB-NES Setup.pdf
USB-NES Lite 5-piece enclosure | $ | 1 | /shell/
Triple 2-input analog multiplexers | @ 74HCT4053 | 1 | https://www.digikey.com/en/products/detail/nexperia-usa-inc/74HCT4053PW-Q100-1/3678979
Dual 4-input analog multiplexers | @ 74HCT4052 | 2 | https://www.digikey.com/en/products/detail/nexperia-usa-inc/74HCT4052PW-118/2530387
7-pin pad port discrete gold pins | @ 3149-2-00-15-00-00-08-0 | 28 | https://www.digikey.com/en/products/detail/mill-max-manufacturing-corp/3149-2-00-15-00-00-08-0/436969
! These resources need to be carefully de-soldered from the blue pill
% PCB manufacturing files for USB-NES-02
* These resources need to be paper-letter printed
$ These resources need to be 3D printed
@ for USB-NES-04 PCB only

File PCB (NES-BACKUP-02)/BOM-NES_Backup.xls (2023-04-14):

PCB reference | part description | part # | link
Q1 | P-channel mosfet | TSM500P02CX | https://www.digikey.ca/product-detail/en/taiwan-semiconductor-corporation/TSM500P02CX-RFG/TSM500P02CXRFGCT-ND/7360424
R1 | 10K resistor, type 0402 | RR0510P-103-D | https://www.digikey.ca/product-detail/en/susumu/RR0510P-103-D/RR05P10.0KDCT-ND/432960
U1 | single tri-state buffer | 74AHCT1G125 | https://www.digikey.ca/product-detail/en/diodes-incorporated/74AHCT1G125SE-7/74AHCT1G125SE-7DICT-ND/2712010

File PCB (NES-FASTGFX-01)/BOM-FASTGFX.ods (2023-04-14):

PCB reference | part description | part # | quantity | link
C1-C7, C13-C18 | 10 nF ceramic capacitor, 0603 package | CL10B103KA8NFNC | 13 | https://www.digikey.ca/en/products/detail/samsung-electro-mechanics/CL10B103KA8NFNC/3887577
C8-C10, C12 | 100 nF ceramic capacitor, 0603 package | CL10F104ZO8NNNC | 4 | https://www.digikey.ca/product-detail/en/samsung-electro-mechanics/CL10F104ZO8NNNC/1276-1258-1-ND/3889344
C11 | 47 uF capacitor | 865080140004 | 1 | https://www.digikey.ca/product-detail/en/wurth-electronics-inc/865080140004/732-8469-1-ND/5728426
IC1 | 32K x 8-bit SRAM | IS62C256AL-45TLI | 1 | https://www.digikey.ca/product-detail/en/issi-integrated-silicon-solution-inc/IS62C256AL-45TLI/706-1109-ND/1557488
IC3 | ATTINY13A-P | ATTINY13A-SSH | 1 | https://www.digikey.ca/product-detail/en/microchip-technology/ATTINY13A-SSH/ATTINY13A-SSH-ND/1995468
U1 | quad 2-input NAND gate | 74HCT00 | 1 | https://www.digikey.ca/product-detail/en/texas-instruments/SN74HCT00PWR/296-8378-1-ND/376720
U2 | 512K x 8-bit flash | SST39SF040-70-4C-WHE | 1 | https://www.digikey.ca/product-detail/en/microchip-technology/SST39SF040-70-4C-WHE/SST39SF040-70-4C-WHE-ND/2297836
 |  |  |  | https://www.aliexpress.com/item/1005002329031941.html
U3 | triple 2-input multiplexer | 74HCT4053 | 1 | https://www.digikey.ca/product-detail/en/nexperia-usa-inc/74HCT4053PW118/1727-4019-1-ND/1944297
U4, U6, U9 | 8-bit register, tristate outputs | 74HCT574 | 3 | https://www.digikey.ca/product-detail/en/nexperia-usa-inc/74HCT574PW118/1727-1530-1-ND/4581031
U5, U8 | 8-bit counter + output register | 74HC590 | 2 | https://www.digikey.ca/product-detail/en/nexperia-usa-inc/74HC590PW118/1727-6614-1-ND/2813814
U10 | dual 2-line to 4-line decoder/demultiplexer | 74HCT139 | 1 | https://www.digikey.ca/product-detail/en/nexperia-usa-inc/74HCT139PW118/1727-6621-1-ND/2813822
U11 | 8-bit tranceiver | 74HCT245 | 1 | https://www.digikey.ca/product-detail/en/nexperia-usa-inc/74HCT245PW118/1727-6353-1-ND/2762864
U12 | single D-type flip-flop | 74AHCT1G79 | 1 | https://www.digikey.ca/product-detail/en/nexperia-usa-inc/74AHCT1G79GW125/1727-6026-1-ND/2753862
U13, U17 | quad 2-input multiplexer | 74HC(T)157 | 2 | https://www.digikey.ca/product-detail/en/on-semiconductor/MC74HC157ADTR2G/MC74HC157ADTR2GOSCT-ND/3487352
U14 | quad 2-input NOR gate | 74HCT02 | 1 | https://www.digikey.com/en/products/detail/texas-instruments/SN74HCT02PWR/1571412
U15 | 8-bit register + clock enable | 74HC(T)377 | 1 | https://www.digikey.ca/product-detail/en/nexperia-usa-inc/74HC377PW118/1727-4297-1-ND/2209914
U16 | 512K x 8-bit SRAM | AS6C4008 | 1 | https://www.digikey.com/en/products/detail/alliance-memory-inc/AS6C4008-55STIN/4234588
Please note that the HCT parts can be swapped with cheaper HC types where applicable.
Also note that DIGIKEY is the easiest and quickest source listed for these parts, but serious deals can be had sourcing some of these parts on eBay and Aliexpress.
When sourcing with Aliexpress and eBay, beware of fake chips: always look for the OEM logo on the chip package in high-quality print and compare with a genuine part, and look at any customer feedback the supplier has received for these parts or similar. If the price seems too good to be true, it’s probably a fake.

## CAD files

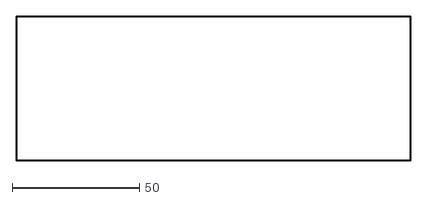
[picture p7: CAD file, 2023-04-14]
PCB (NES-BACKUP-02)/NES_Backup_v02/NES_backup-Edge.Cuts.dxf
155.2 x 56.8

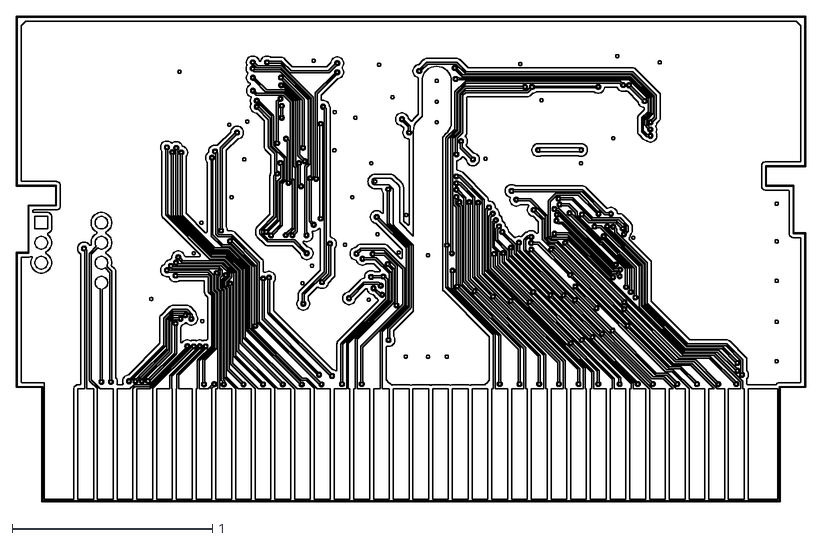
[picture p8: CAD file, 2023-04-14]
PCB (NES-FASTGFX-01)/FASTGFX_v01/cart-B_Cu.dxf
3.94 x 2.42

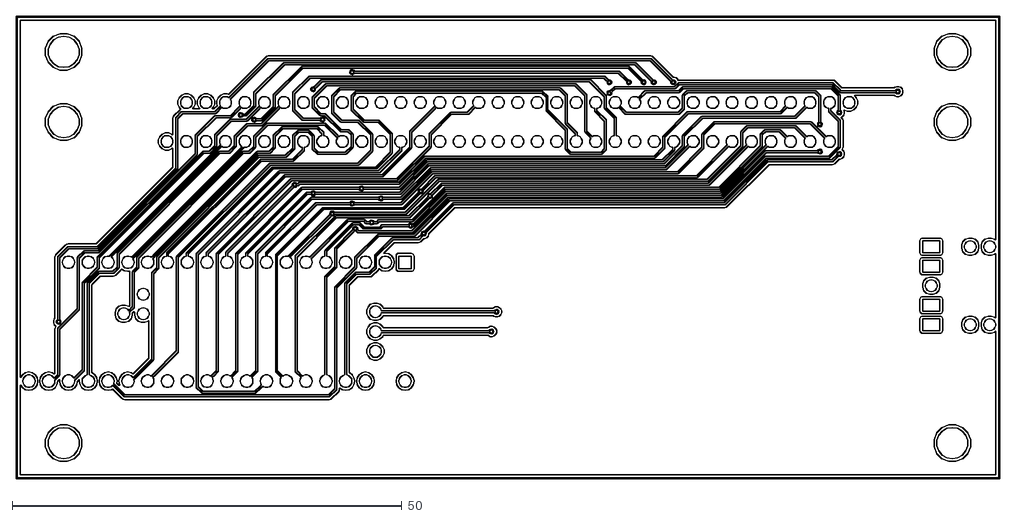
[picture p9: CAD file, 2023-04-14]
PCB (USB-NES-02)/USB-NES_v02/NES_backup-B.Cu.dxf
126.1 x 59.4

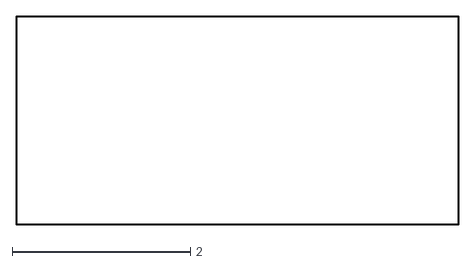
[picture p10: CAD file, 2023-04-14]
PCB (USB-NES-04)/USB-NES_v04/NES_backup-Edge_Cuts.dxf
4.97 x 2.34

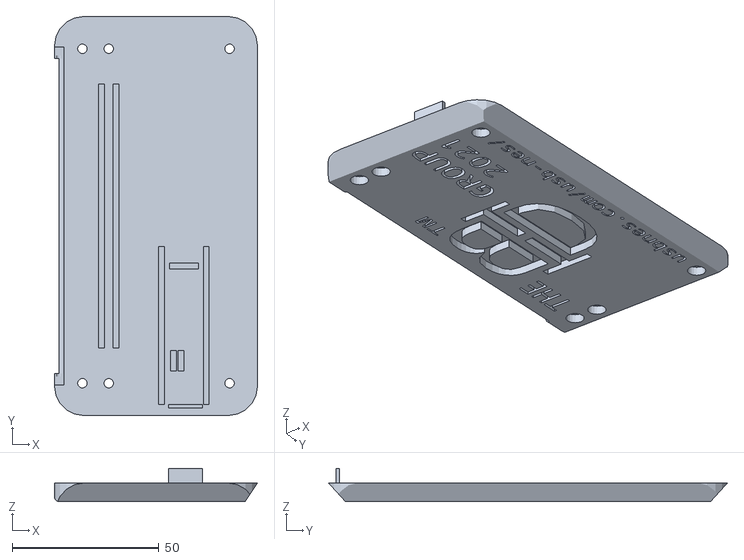
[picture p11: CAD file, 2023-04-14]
shell/06-26-2021 USB-NES Lite Bottom.stl
69.2 x 136.0 x 11.3

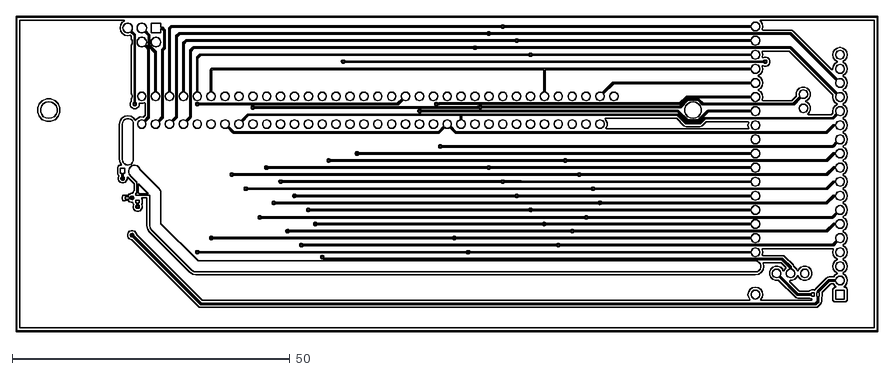
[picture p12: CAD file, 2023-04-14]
PCB (NES-BACKUP-02)/NES_Backup_v02/NES_backup-F.Cu.dxf
155.2 x 56.8

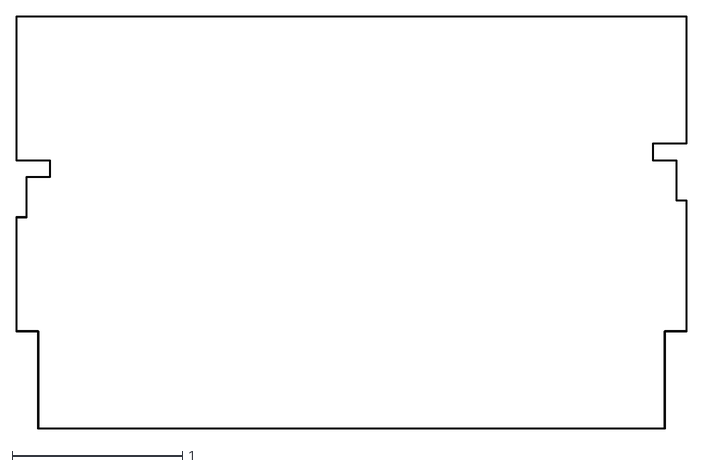
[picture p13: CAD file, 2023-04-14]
PCB (NES-FASTGFX-01)/FASTGFX_v01/cart-Edge_Cuts.dxf
3.94 x 2.42

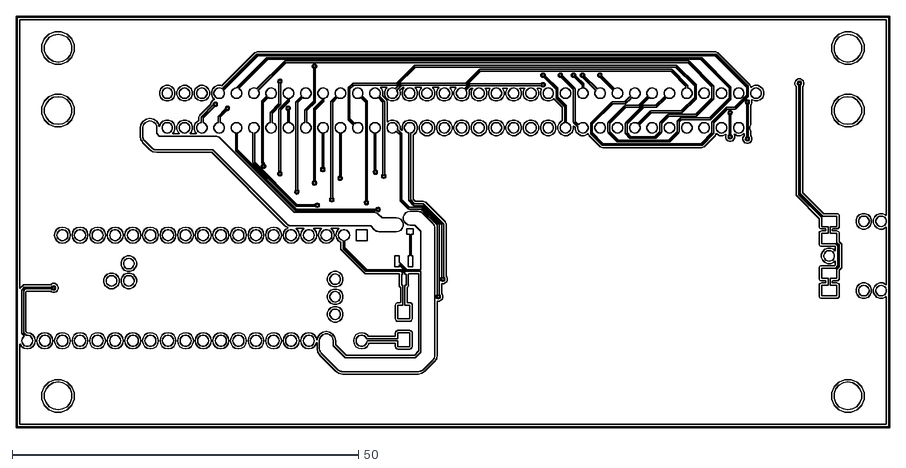
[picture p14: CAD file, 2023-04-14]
PCB (USB-NES-02)/USB-NES_v02/NES_backup-F.Cu.dxf
126.1 x 59.4

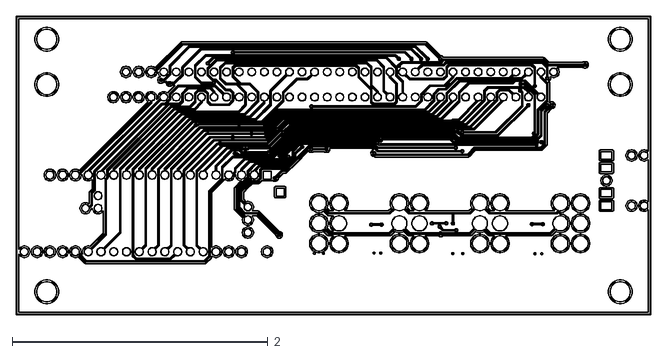
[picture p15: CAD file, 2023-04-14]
PCB (USB-NES-04)/USB-NES_v04/NES_backup-B_Cu.dxf
4.97 x 2.34

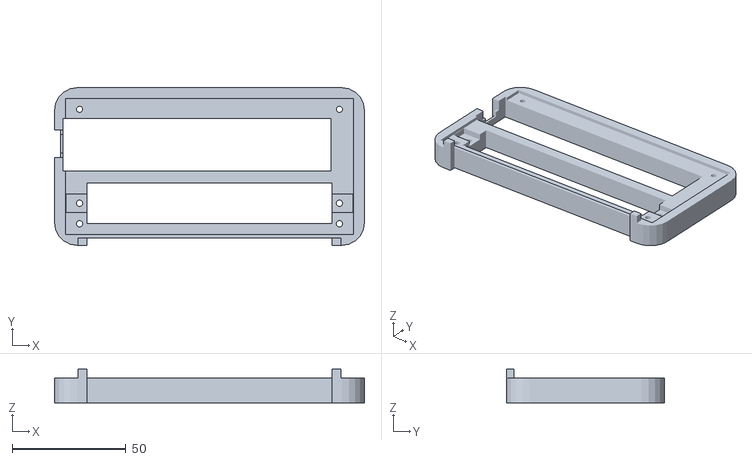
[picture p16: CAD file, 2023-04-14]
shell/07-07-2021 USB-NES Lite Middle.stl
136.0 x 69.2 x 14.7

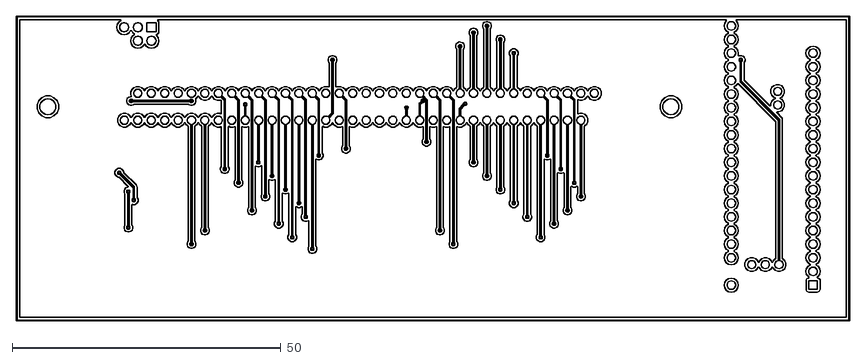
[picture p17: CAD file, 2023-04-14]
PCB (NES-BACKUP-02)/NES_Backup_v02/NES_backup-B.Cu.dxf
155.2 x 56.8

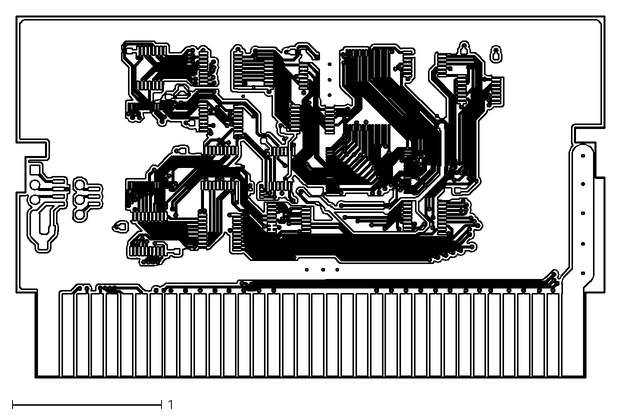
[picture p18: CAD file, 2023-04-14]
PCB (NES-FASTGFX-01)/FASTGFX_v01/cart-F_Cu.dxf
3.94 x 2.42

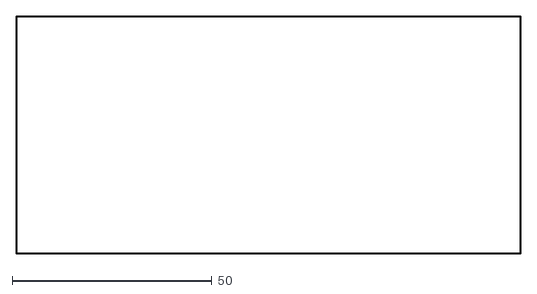
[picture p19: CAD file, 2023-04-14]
PCB (USB-NES-02)/USB-NES_v02/NES_backup-Edge.Cuts.dxf
126.1 x 59.4

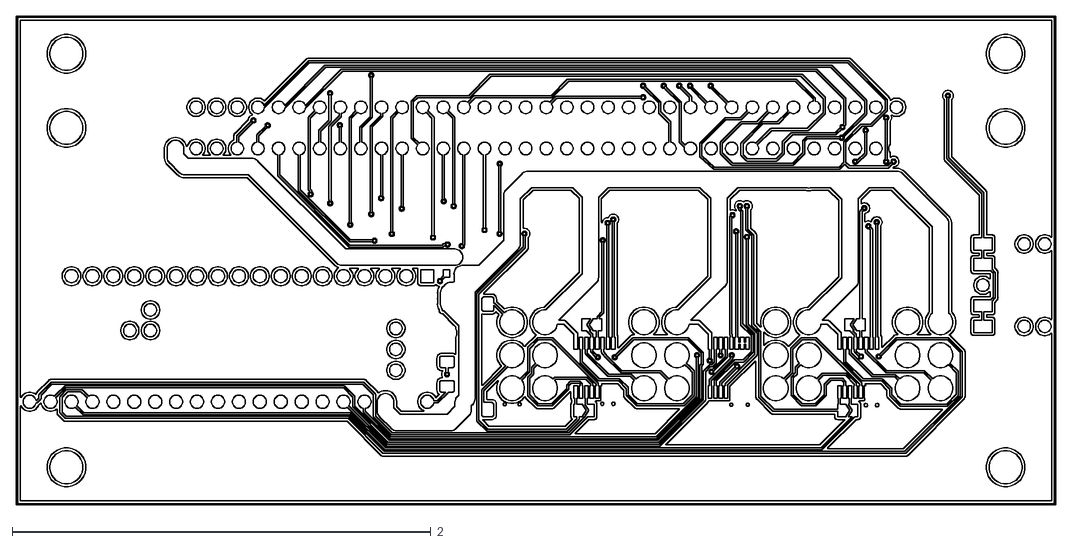
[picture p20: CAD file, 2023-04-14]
PCB (USB-NES-04)/USB-NES_v04/NES_backup-F_Cu.dxf
4.97 x 2.34

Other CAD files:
shell/06-27-2021 USB-NES Lite Dust Cover Hinge.stl
shell/(alternate) USB-NES Lite Bottom (no lettering).stl
shell/03-07-2021 USB-NES Lite Reset Button.stl
shell/06-24-2021 USB-NES Lite Top.stl
PCB (NES-BACKUP-02)/NES_Backup_v02/NES_backup-B.Mask.dxf
PCB (NES-BACKUP-02)/NES_Backup_v02/NES_backup-F.Mask.dxf
PCB (NES-BACKUP-02)/NES_Backup_v02/NES_backup-F.SilkS.dxf
PCB (NES-FASTGFX-01)/FASTGFX_v01/cart-B_Mask.dxf
PCB (NES-FASTGFX-01)/FASTGFX_v01/cart-B_SilkS.dxf
PCB (NES-FASTGFX-01)/FASTGFX_v01/cart-F_Mask.dxf
PCB (NES-FASTGFX-01)/FASTGFX_v01/cart-F_SilkS.dxf
PCB (USB-NES-02)/USB-NES_v02/NES_backup-B.Mask.dxf
PCB (USB-NES-02)/USB-NES_v02/NES_backup-F.Mask.dxf
PCB (USB-NES-02)/USB-NES_v02/NES_backup-F.SilkS.dxf
PCB (USB-NES-04)/USB-NES_v04/NES_backup-B_Mask.dxf
PCB (USB-NES-04)/USB-NES_v04/NES_backup-F_Mask.dxf
PCB (USB-NES-04)/USB-NES_v04/NES_backup-F_SilkS.dxf

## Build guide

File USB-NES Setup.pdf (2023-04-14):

Feb 12 2023

Dear customer,

Thank you for purchasing USB-NES Lite. Please visit usbnes.com for more info.

Quick Start Guide
1. Open the dust cover door on USB-NES and plug a clean NES cartridge into the slot.
2. Plug the unit into a host computer using the micro USB cord included.
A red lamp on the console will light up; this indicates the unit has power.
A green lamp will also momentarily illuminate; this is USB-NES auto-detecting the cartridge boardset.
3. Open your favourite NES emulator and under the FILE menu, select OPEN ROM...
4. Navigate to the USB-NES root directory and select the ROM.NES file to load the game. At this point a green lamp on the console will light up indicating the cartridge is powered up and being read by the host.
5. Once the ROM.NES file loads, the green lamp turns off and it is then safe to remove the cartridge from USB-NES.
6. To play the next cartridge game just pop it into USB-NES and read/open the DETECT.TXT file. Accessing the DETECT.TXT file causes USB-NES to re-identify the boardset in the cartridge, which occurs automatically when the unit is plugged into the host initially. Once the DETECT.TXT data is read out, the next cartridge ROM.NES file is ready to load into the emulator.

Notes
- USB-NES will detect if your game has a functioning save RAM system, and expose the data (usually 8KB) as a ROM.SAV file in the root directory of USB-NES that can be read or overwritten.
- You _may_ assign the SAVE RAM path in your emulator directly to the USB-NES drive and this will work to give the emulator seamless access to the battery-backed save RAM on the cart. However if you do this, be careful to NOT change the game cartridge out before the end of your game session or you may end up writing the save data to the wrong cartridge inadvertently when quitting. Generally, the emulator writes to the ROM.SAV file once, usually when quitting the ROM emulation.
- The save RAM detection used in USB-NES is still a work in progress. It may identify a cart to have save RAM but have no actual battery in it, which is mostly harmless. However if it can't identify any save RAM on a cart you know should have it, you will probably have to replace the battery inside the cart to fix the issue.
- USB-NES has a lot of features, including the ability to augment the unit with custom mapper override scripts that can be programmed into the auto-detection sequence. Mapper override scripts provide a way to teach USB-NES how to read unsupported boardset types.
(see "Map Overrides" and "Cart Compatibility" sections of the website for details)
- Most mapper identification tests are built-in to the USB-NES firmware but the BCMTABLE.BIN file contains the entire listing of bus-conflict mapper types supported by USB-NES. It may be edited or customized by the user to support other unknown or uncommon boardset types with bus conflicts. Note this is strictly a binary-formatted file, so you will need to use a hex editor to edit the BCMTABLE.BIN file if desired. (see the "BCMTABLE Documentation" section of the website for details)
- Please refer to our Troubleshooting and Forums section of the website if you have problems using USB-NES.

Sincerely,

Brad Taylor
Proprietor
BTTD Group

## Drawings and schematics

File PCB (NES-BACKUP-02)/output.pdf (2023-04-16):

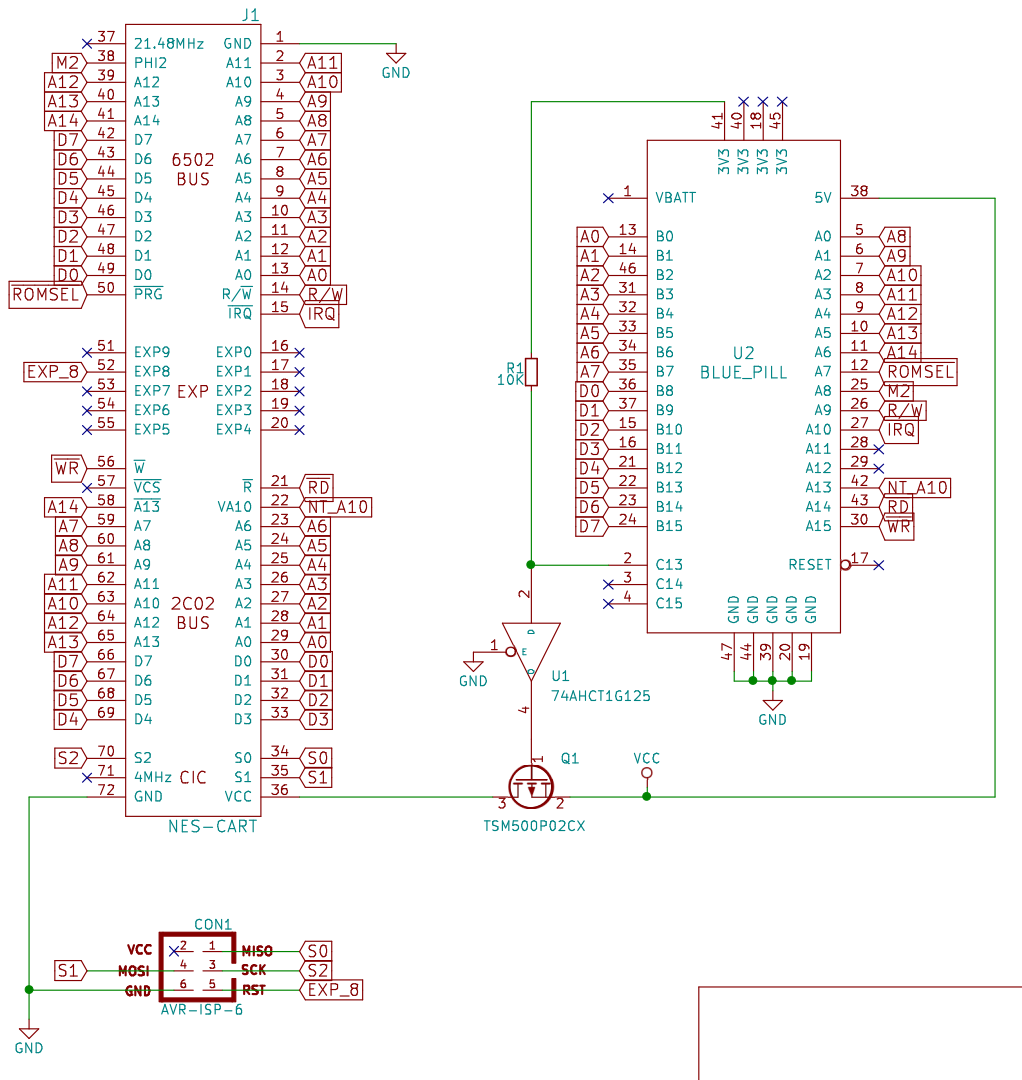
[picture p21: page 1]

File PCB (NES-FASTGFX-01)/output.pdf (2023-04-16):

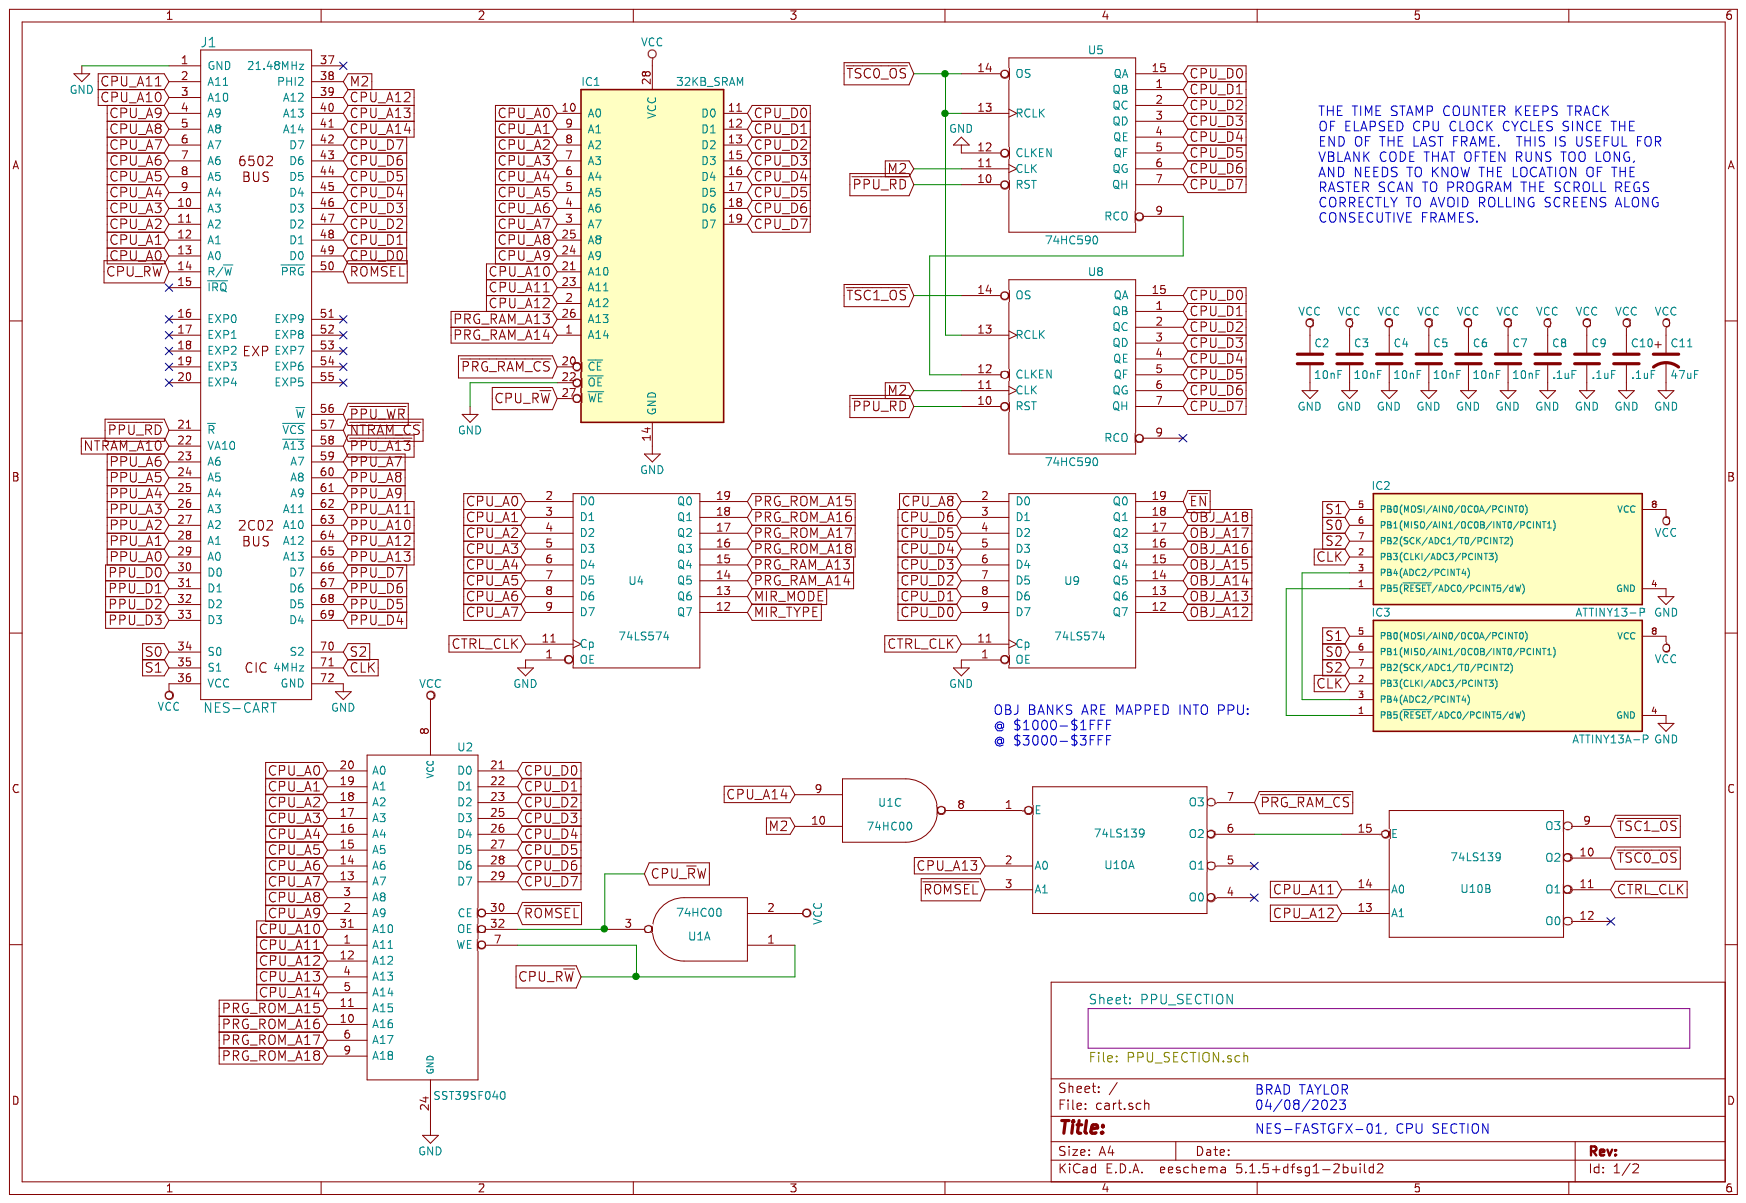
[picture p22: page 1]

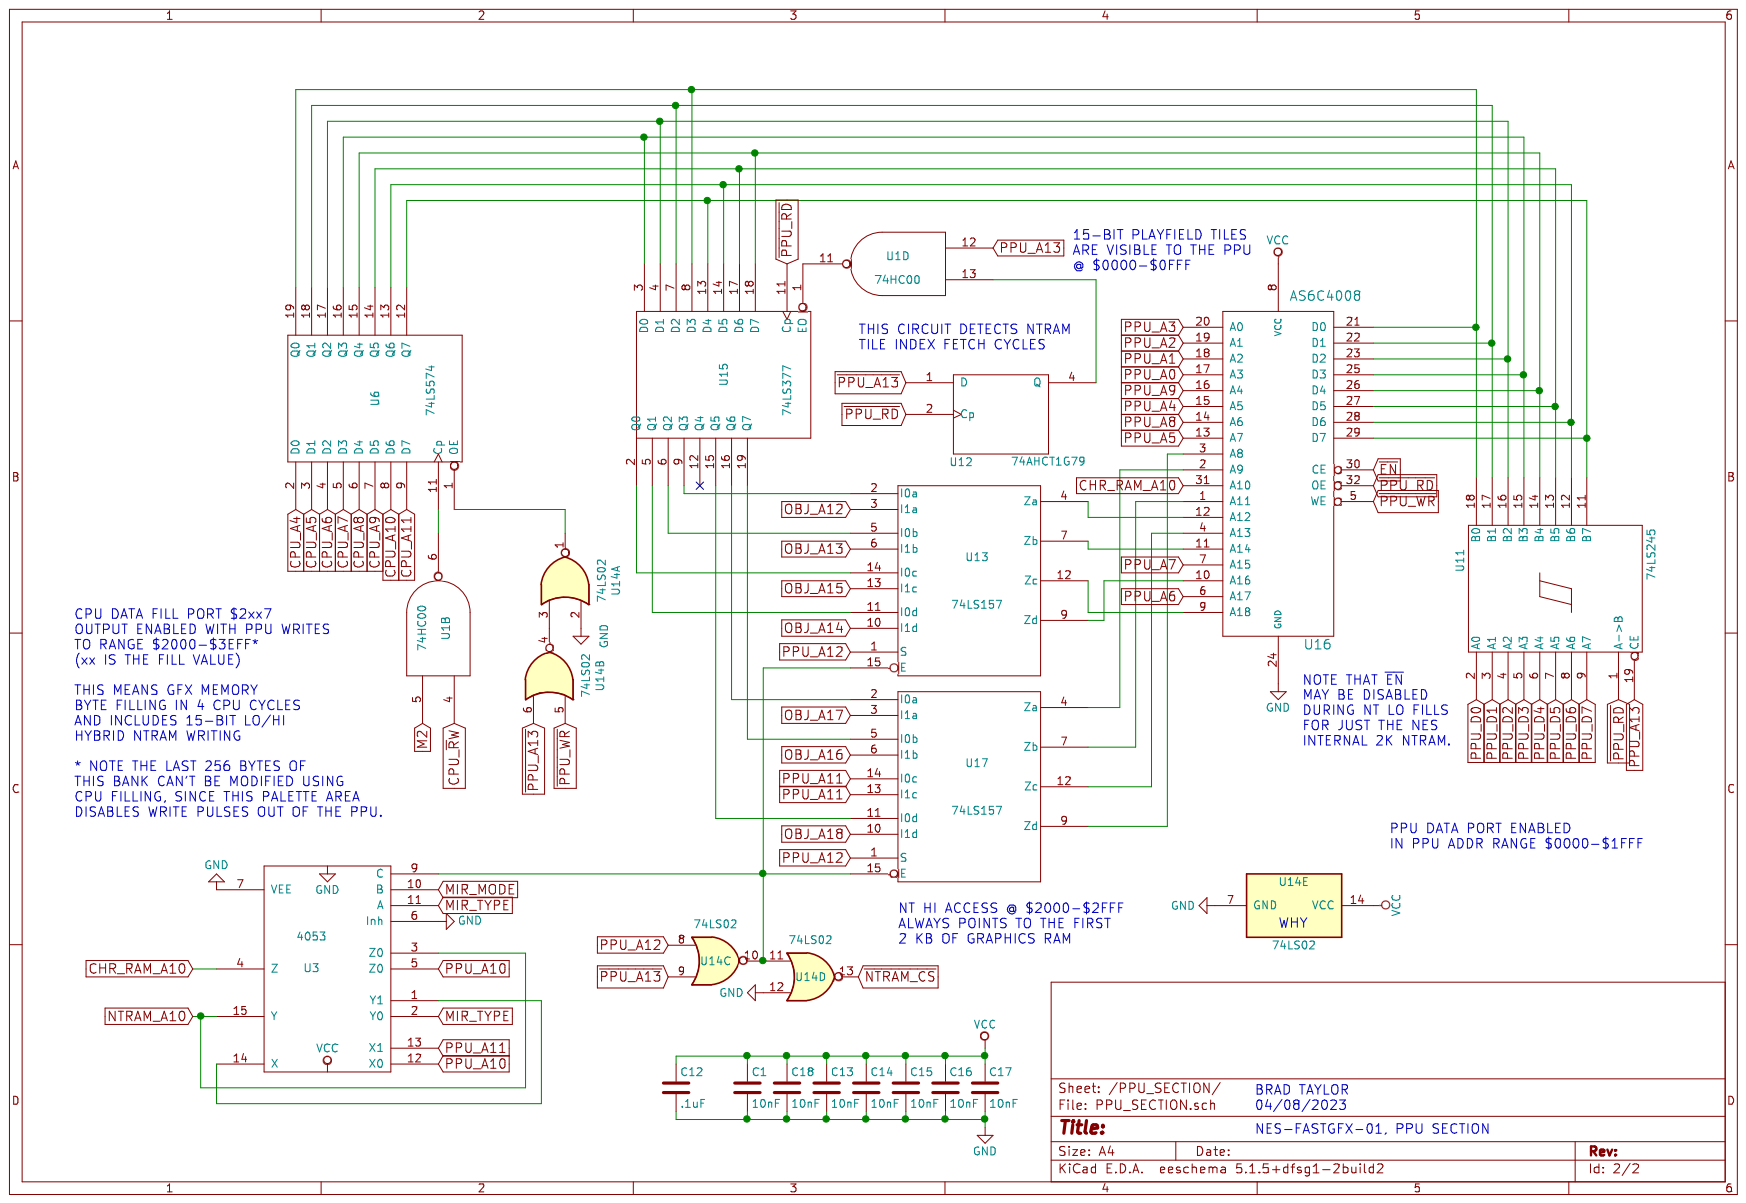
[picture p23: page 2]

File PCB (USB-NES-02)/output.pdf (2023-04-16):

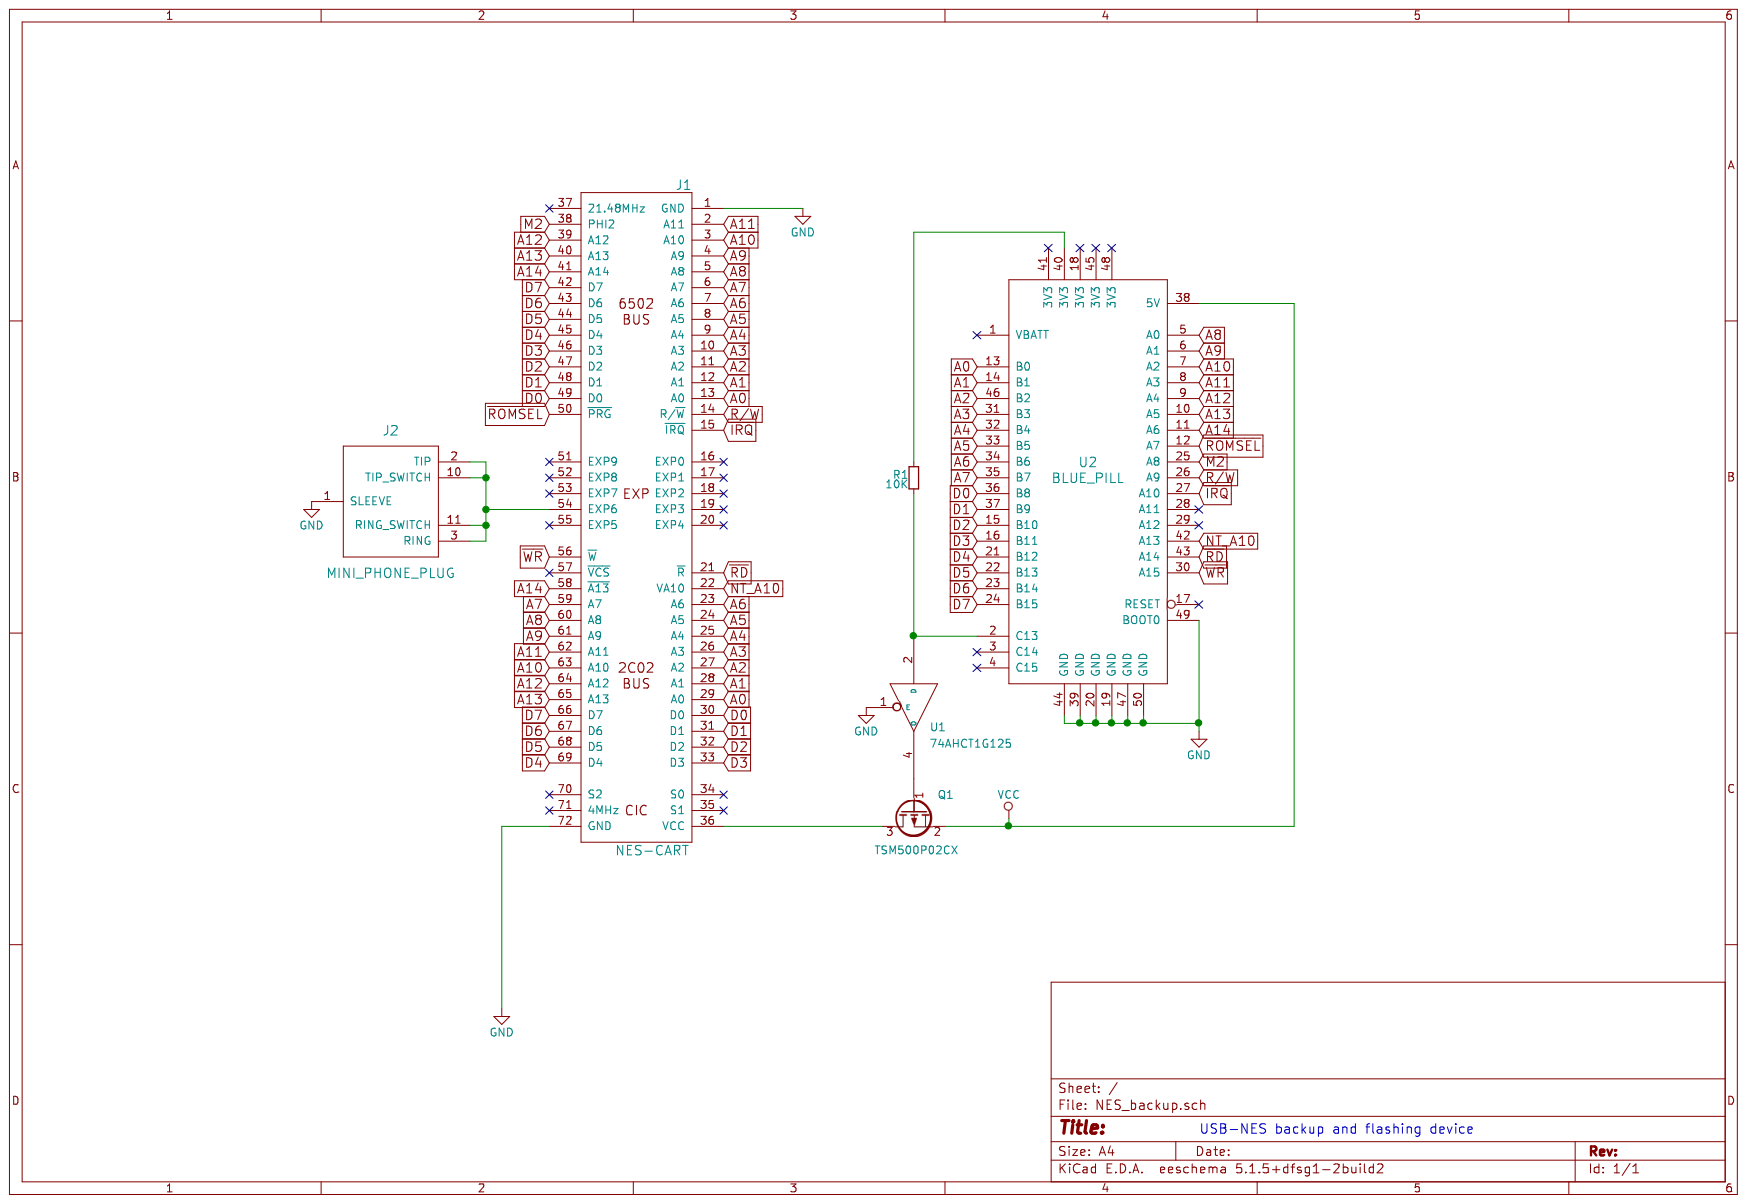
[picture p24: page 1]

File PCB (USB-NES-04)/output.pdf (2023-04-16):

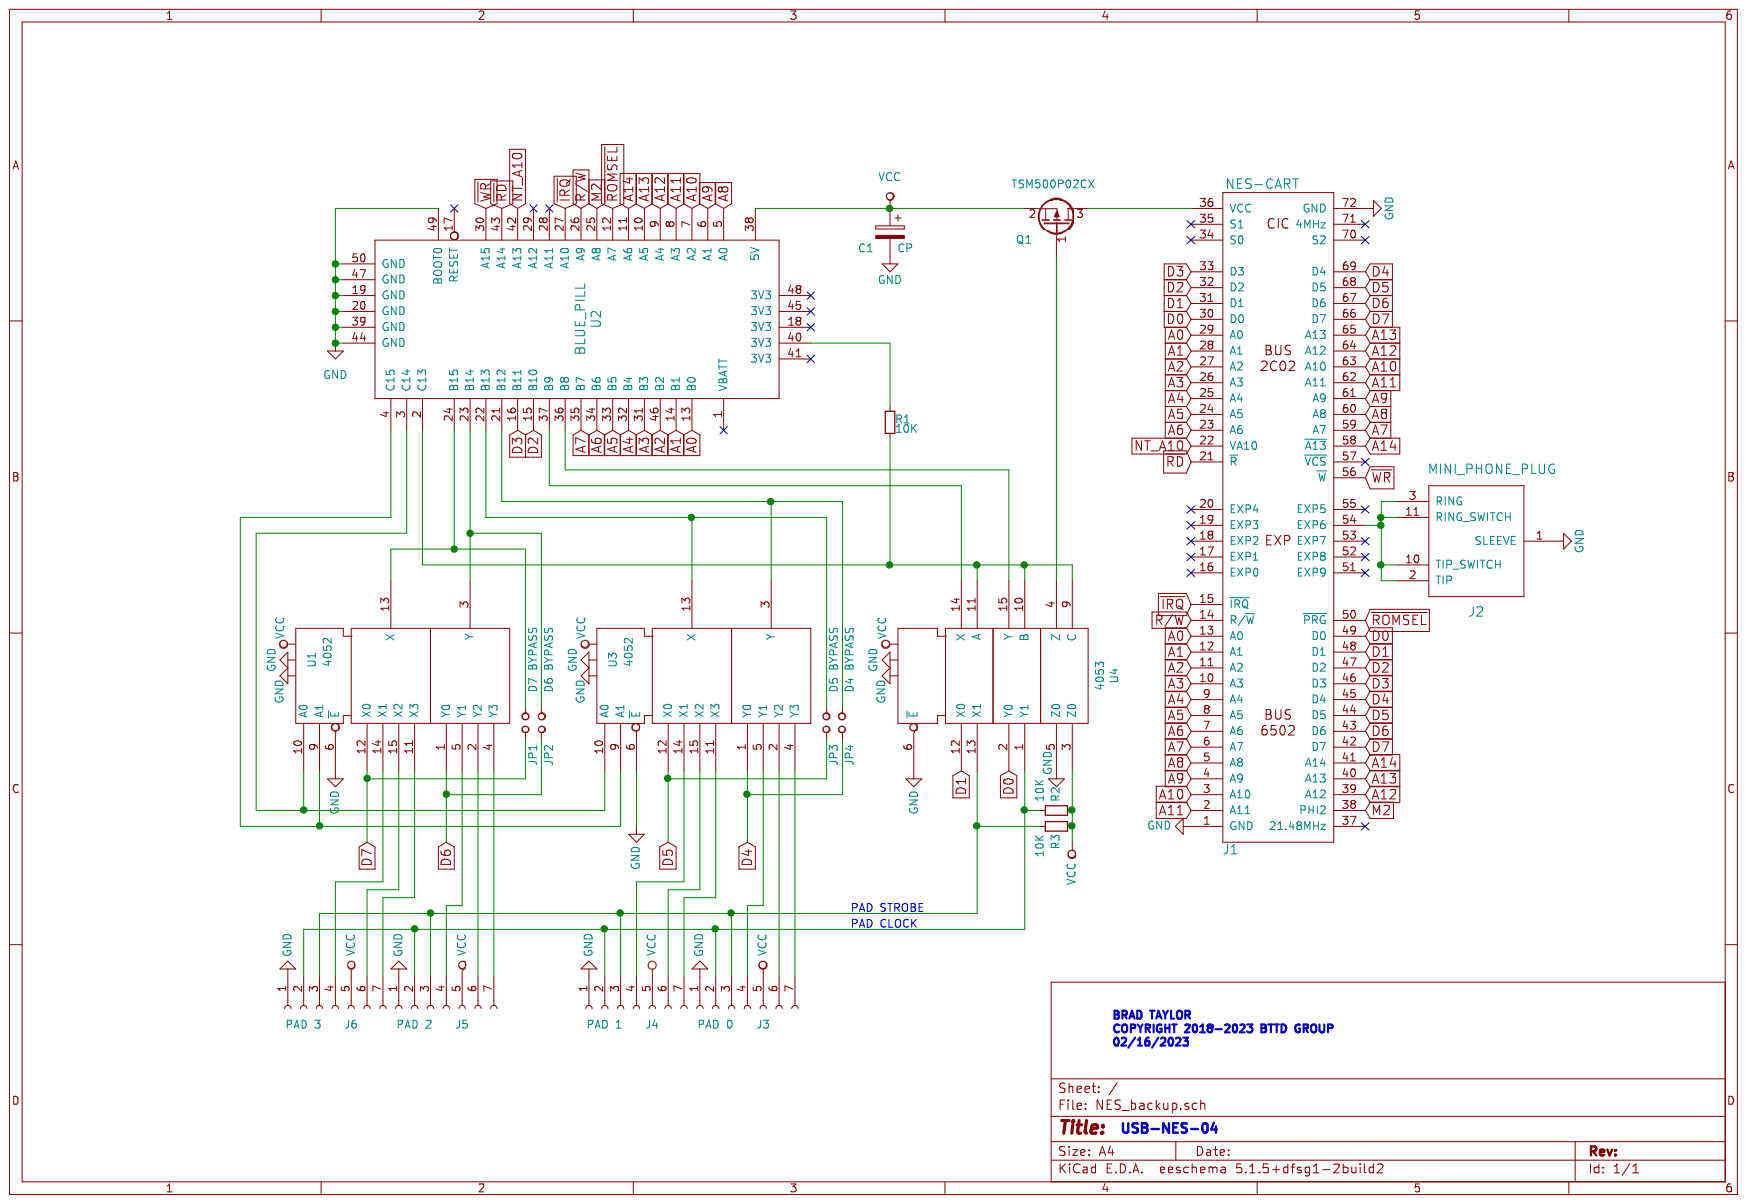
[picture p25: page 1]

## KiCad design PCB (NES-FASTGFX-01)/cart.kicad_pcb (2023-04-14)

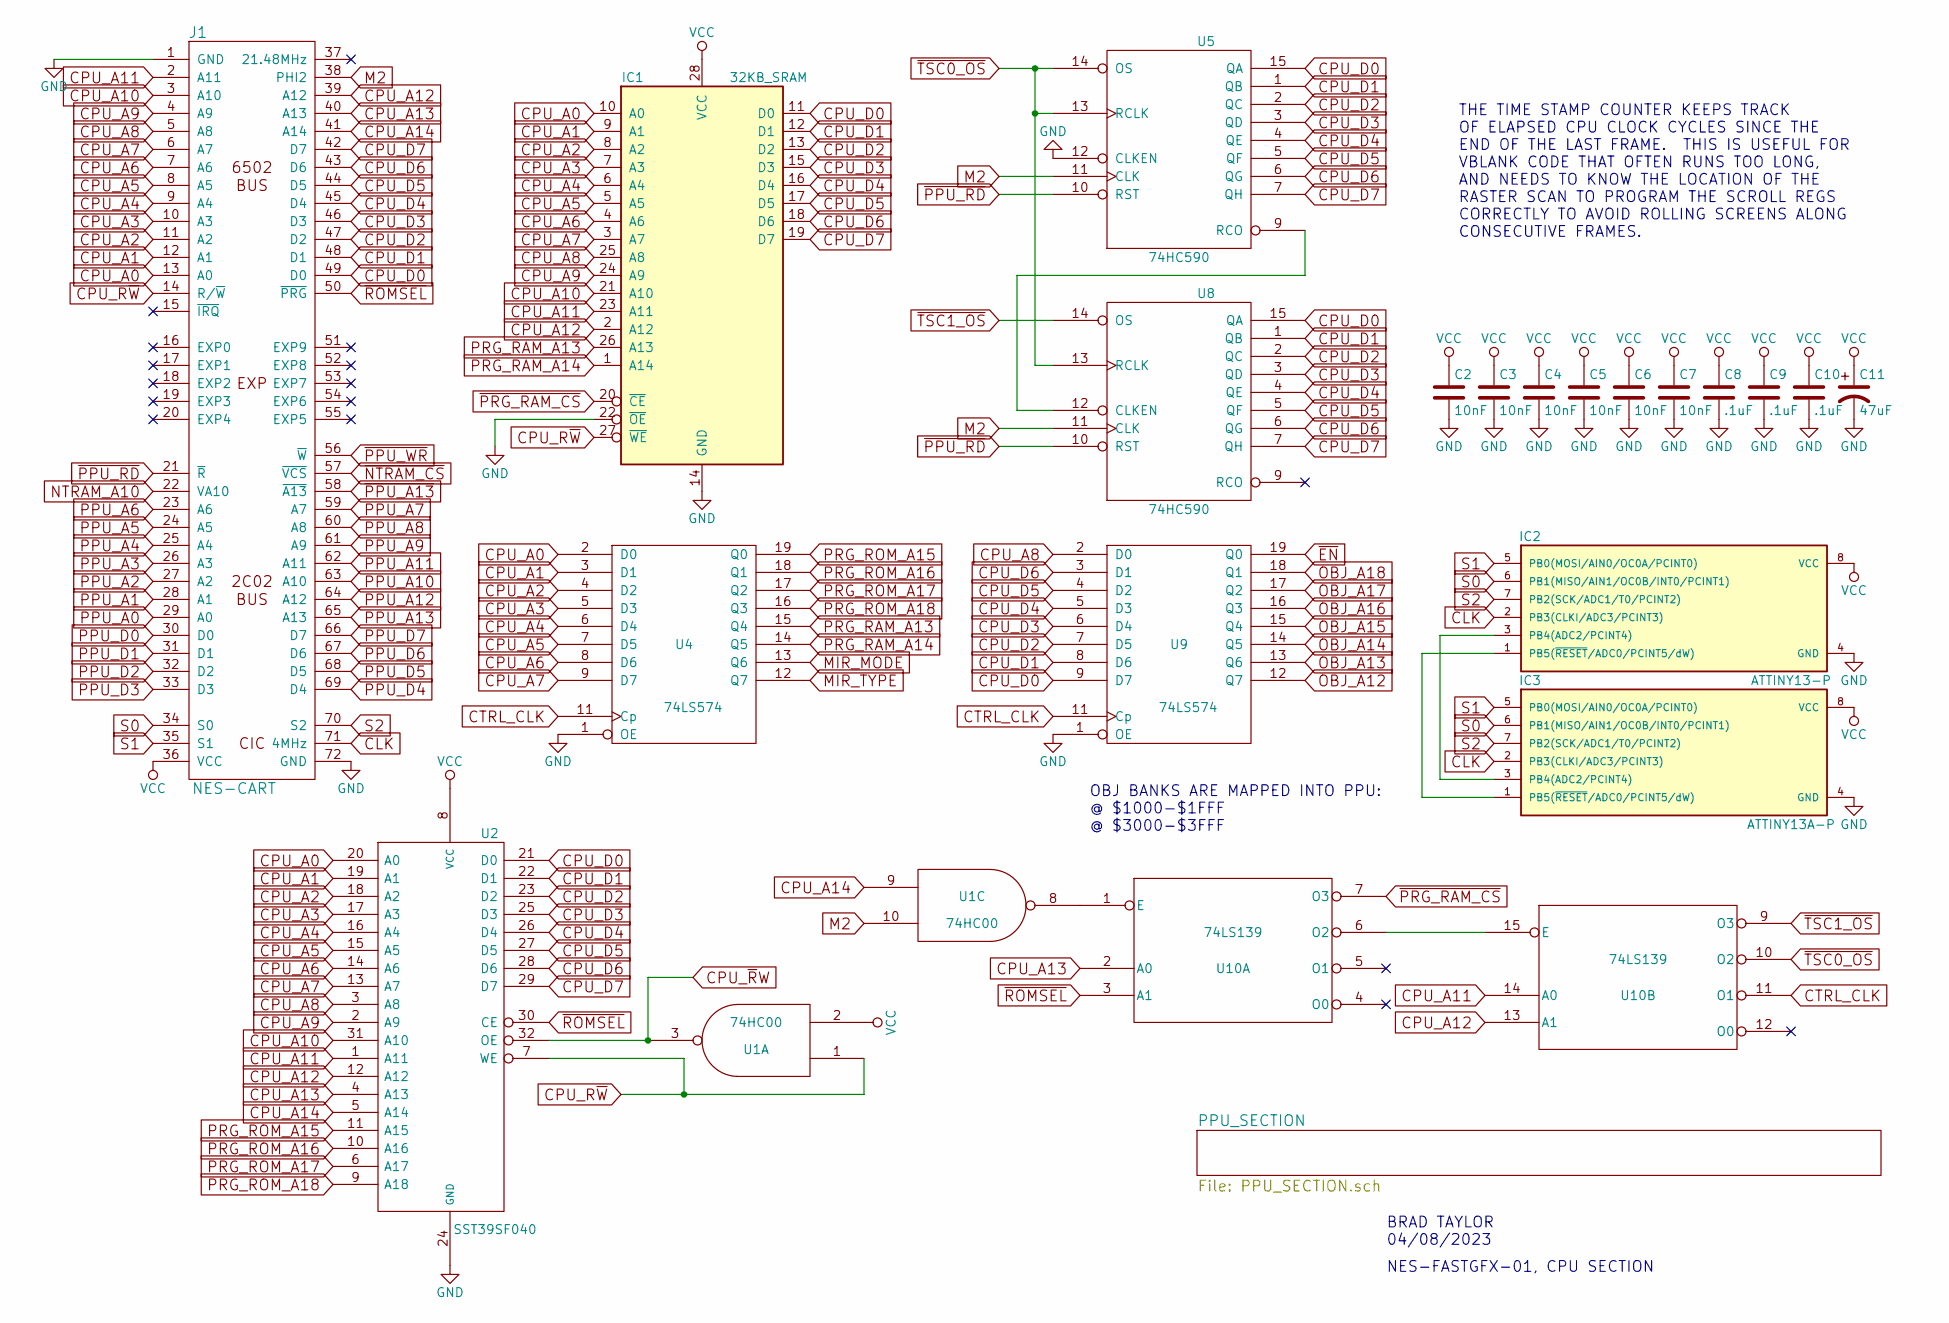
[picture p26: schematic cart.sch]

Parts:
C2, C3, C4, C5, C6, C7: 10nF; C_0603_1608Metric_Pad1.05x0.95mm_HandSolder
C8, C9, C10: .1uF; C_0603_1608Metric_Pad1.05x0.95mm_HandSolder
C11: 47uF; CP_Elec_4x5.3
IC1: 32KB_SRAM; SOIC-28
IC2: ATTINY13-P; DIP-8_W7.62mm
IC3: ATTINY13A-P; SOIC-8_3.9x4.9mm_P1.27mm
J1: NES-CART; NES_CART_FINGERS
U1: 74HC00; TSSOP-14_4.4x5mm_P0.65mm
U2: SST39SF040; SOIC-32
U4, U9: 74LS574; TSSOP-20_4.4x6.5mm_P0.65mm
U5, U8: 74HC590; TSSOP-16_4.4x5mm_P0.65mm
U10: 74LS139; TSSOP-16_4.4x5mm_P0.65mm

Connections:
CLK: IC2.2 (PB3(CLKI/ADC3/PCINT3)), IC3.2 (PB3(CLKI/ADC3/PCINT3)), J1.71 (4MHz)
CPU_A0: IC1.10 (A0), J1.13 (A0), U2.20 (A0), U4.2 (D0)
CPU_A1: IC1.9 (A1), J1.12 (A1), U2.19 (A1), U4.3 (D1)
CPU_A2: IC1.8 (A2), J1.11 (A2), U2.18 (A2), U4.4 (D2)
CPU_A3: IC1.7 (A3), J1.10 (A3), U2.17 (A3), U4.5 (D3)
CPU_A4: IC1.6 (A4), J1.9 (A4), U2.16 (A4), U4.6 (D4); also elsewhere on the board
CPU_A5: IC1.5 (A5), J1.8 (A5), U2.15 (A5), U4.7 (D5); also elsewhere on the board
CPU_A6: IC1.4 (A6), J1.7 (A6), U2.14 (A6), U4.8 (D6); also elsewhere on the board
CPU_A7: IC1.3 (A7), J1.6 (A7), U2.13 (A7), U4.9 (D7); also elsewhere on the board
CPU_A8: IC1.25 (A8), J1.5 (A8), U2.3 (A8), U9.2 (D0); also elsewhere on the board
CPU_A9: IC1.24 (A9), J1.4 (A9), U2.2 (A9); also elsewhere on the board
CPU_A10: IC1.21 (A10), J1.3 (A10), U2.31 (A10); also elsewhere on the board
CPU_A11: IC1.23 (A11), J1.2 (A11), U2.1 (A11), U10.14 (A0); also elsewhere on the board
CPU_A12: IC1.2 (A12), J1.39 (A12), U2.12 (A12), U10.13 (A1)
CPU_A13: J1.40 (A13), U2.4 (A13), U10.2 (A0)
CPU_A14: J1.41 (A14), U1.9, U2.5 (A14)
CPU_D0: IC1.11 (D0), J1.49 (D0), U2.21 (D0), U5.15 (QA), U8.15 (QA), U9.9 (D7)
CPU_D1: IC1.12 (D1), J1.48 (D1), U2.22 (D1), U5.1 (QB), U8.1 (QB), U9.8 (D6)
CPU_D2: IC1.13 (D2), J1.47 (D2), U2.23 (D2), U5.2 (QC), U8.2 (QC), U9.7 (D5)
CPU_D3: IC1.15 (D3), J1.46 (D3), U2.25 (D3), U5.3 (QD), U8.3 (QD), U9.6 (D4)
CPU_D4: IC1.16 (D4), J1.45 (D4), U2.26 (D4), U5.4 (QE), U8.4 (QE), U9.5 (D3)
CPU_D5: IC1.17 (D5), J1.44 (D5), U2.27 (D5), U5.5 (QF), U8.5 (QF), U9.4 (D2)
CPU_D6: IC1.18 (D6), J1.43 (D6), U2.28 (D6), U5.6 (QG), U8.6 (QG), U9.3 (D1)
CPU_D7: IC1.19 (D7), J1.42 (D7), U2.29 (D7), U5.7 (QH), U8.7 (QH)
CPU_R~W: IC1.27 (~WE~), J1.14 (R/~W), U1.1, U2.7 (WE)
CPU_~R~W: U1.3, U2.32 (OE); also elsewhere on the board
CTRL_CLK: U4.11 (Cp), U9.11 (Cp), U10.11 (O1)
GND: C2.2, C3.2, C4.2, C5.2, C6.2, C7.2, C8.2, C9.2, C10.2, C11.2, IC1.14 (GND), IC1.22 (~OE~), IC2.4 (GND), IC3.4 (GND), J1.1 (GND), J1.72 (GND), U1.7 (GND), U2.24 (GND), U4.1 (OE), U4.10 (GND), U5.8 (GND), U5.12 (CLKEN), U8.8 (GND), U9.1 (OE), U9.10 (GND), U10.8 (GND); also elsewhere on the board
M2: J1.38 (PHI2), U1.10, U5.11 (CLK), U8.11 (CLK); also elsewhere on the board
MIR_MODE: U4.13 (Q6); also elsewhere on the board
MIR_TYPE: U4.12 (Q7); also elsewhere on the board
NTRAM_A10: J1.22 (VA10); also elsewhere on the board
unnamed: IC2.1 (PB5(~RESET~/ADC0/PCINT5/dW)), IC3.1 (PB5(~RESET~/ADC0/PCINT5/dW))
unnamed: IC2.3 (PB4(ADC2/PCINT4)), IC3.3 (PB4(ADC2/PCINT4))
unnamed: U1.8, U10.1 (E)
unnamed: U5.9 (RCO), U8.12 (CLKEN)
unnamed: U10.6 (O2), U10.15 (E)
OBJ_A12: U9.12 (Q7); also elsewhere on the board
OBJ_A13: U9.13 (Q6); also elsewhere on the board
OBJ_A14: U9.14 (Q5); also elsewhere on the board
OBJ_A15: U9.15 (Q4); also elsewhere on the board
OBJ_A16: U9.16 (Q3); also elsewhere on the board
OBJ_A17: U9.17 (Q2); also elsewhere on the board
OBJ_A18: U9.18 (Q1); also elsewhere on the board
PPU_A0: J1.29 (A0); also elsewhere on the board
PPU_A1: J1.28 (A1); also elsewhere on the board
PPU_A2: J1.27 (A2); also elsewhere on the board
PPU_A3: J1.26 (A3); also elsewhere on the board
PPU_A4: J1.25 (A4); also elsewhere on the board
PPU_A5: J1.24 (A5); also elsewhere on the board
PPU_A6: J1.23 (A6); also elsewhere on the board
PPU_A7: J1.59 (A7); also elsewhere on the board
PPU_A8: J1.60 (A8); also elsewhere on the board
PPU_A9: J1.61 (A9); also elsewhere on the board
PPU_A10: J1.63 (A10); also elsewhere on the board
PPU_A11: J1.62 (A11); also elsewhere on the board
PPU_A12: J1.64 (A12); also elsewhere on the board
PPU_A13: J1.65 (A13); also elsewhere on the board
PPU_D0: J1.30 (D0); also elsewhere on the board
PPU_D1: J1.31 (D1); also elsewhere on the board
PPU_D2: J1.32 (D2); also elsewhere on the board
PPU_D3: J1.33 (D3); also elsewhere on the board
PPU_D4: J1.69 (D4); also elsewhere on the board
PPU_D5: J1.68 (D5); also elsewhere on the board
PPU_D6: J1.67 (D6); also elsewhere on the board
PPU_D7: J1.66 (D7); also elsewhere on the board
PRG_RAM_A13: IC1.26 (A13), U4.15 (Q4)
PRG_RAM_A14: IC1.1 (A14), U4.14 (Q5)
PRG_ROM_A15: U2.11 (A15), U4.19 (Q0)
PRG_ROM_A16: U2.10 (A16), U4.18 (Q1)
PRG_ROM_A17: U2.6 (A17), U4.17 (Q2)
PRG_ROM_A18: U2.9 (A18), U4.16 (Q3)
S0: IC2.6 (PB1(MISO/AIN1/OC0B/INT0/PCINT1)), IC3.6 (PB1(MISO/AIN1/OC0B/INT0/PCINT1)), J1.34 (S0)
S1: IC2.5 (PB0(MOSI/AIN0/OC0A/PCINT0)), IC3.5 (PB0(MOSI/AIN0/OC0A/PCINT0)), J1.35 (S1)
S2: IC2.7 (PB2(SCK/ADC1/T0/PCINT2)), IC3.7 (PB2(SCK/ADC1/T0/PCINT2)), J1.70 (S2)
VCC: C2.1, C3.1, C4.1, C5.1, C6.1, C7.1, C8.1, C9.1, C10.1, C11.1, IC1.28 (VCC), IC2.8 (VCC), IC3.8 (VCC), J1.36 (VCC), U1.2, U1.14 (VCC), U2.8 (VCC), U4.20 (VCC), U5.16 (VCC), U8.16 (VCC), U9.20 (VCC), U10.16 (VCC); also elsewhere on the board
~EN: U9.19 (Q0); also elsewhere on the board
~NTRAM_CS: J1.57 (~VCS); also elsewhere on the board
~PPU_A13: J1.58 (~A13); also elsewhere on the board
~PPU_RD: J1.21 (~R), U5.10 (RST), U8.10 (RST); also elsewhere on the board
~PPU_WR: J1.56 (~W); also elsewhere on the board
~PRG_RAM_CS: IC1.20 (~CE~), U10.7 (O3)
~ROMSEL: J1.50 (~PRG), U2.30 (CE), U10.3 (A1)
~TSC0_OS: U5.13 (RCLK), U5.14 (OS), U8.13 (RCLK), U10.10 (O2)
~TSC1_OS: U8.14 (OS), U10.9 (O3)

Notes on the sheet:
NES-FASTGFX-01, CPU SECTION
BRAD TAYLOR 04/08/2023
OBJ BANKS ARE MAPPED INTO PPU: @ $1000-$1FFF @ $3000-$3FFF
THE TIME STAMP COUNTER KEEPS TRACK OF ELAPSED CPU CLOCK CYCLES SINCE THE END OF THE LAST FRAME. THIS IS USEFUL FOR VBLANK CODE THAT OFTEN RUNS TOO LONG, AND NEEDS TO KNOW THE LOCATION OF THE RASTER SCAN TO PROGRAM THE SCROLL REGS CORRECTLY TO AVOID ROLLING SCREENS ALONG CONSECUTIVE FRAMES.

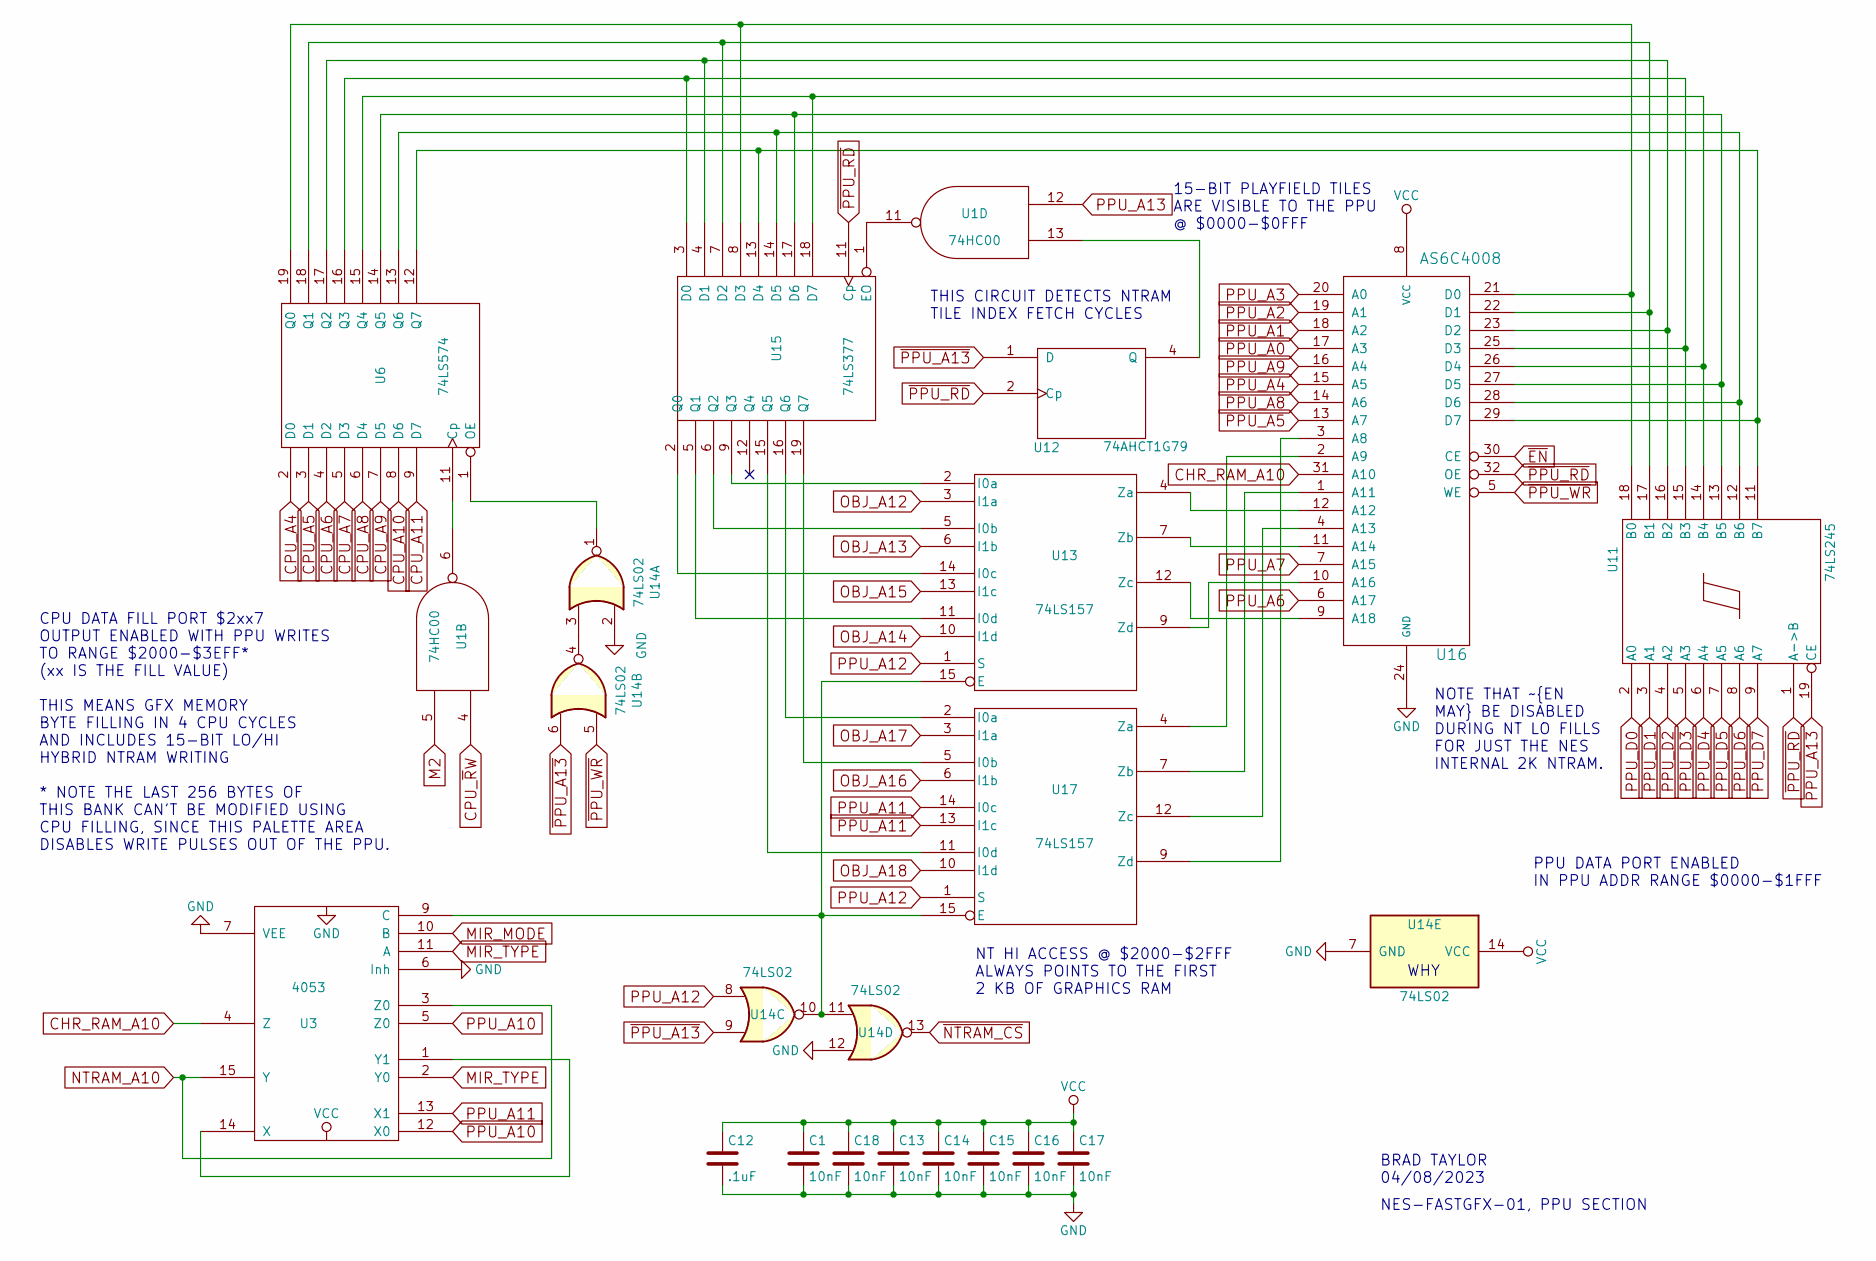
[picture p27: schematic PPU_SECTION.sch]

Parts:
C1, C13, C14, C15, C16, C17, C18: 10nF; C_0603_1608Metric_Pad1.05x0.95mm_HandSolder
C12: .1uF; C_0603_1608Metric_Pad1.05x0.95mm_HandSolder
U1: 74HC00; TSSOP-14_4.4x5mm_P0.65mm
U3: 4053; TSSOP-16_4.4x5mm_P0.65mm
U6: 74LS574; TSSOP-20_4.4x6.5mm_P0.65mm
U11: 74LS245; TSSOP-20_4.4x6.5mm_P0.65mm
U12: 74AHCT1G79; SOT-353_SC-70-5
U13, U17: 74LS157; TSSOP-16_4.4x5mm_P0.65mm
U14: 74LS02; TSSOP-14_4.4x5mm_P0.65mm
U15: 74LS377; TSSOP-20_4.4x6.5mm_P0.65mm
U16: AS6C4008; SOIC-32

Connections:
CHR_RAM_A10: U3.4 (Z), U16.31 (A10)
CPU_A4: U6.2 (D0); also elsewhere on the board
CPU_A5: U6.3 (D1); also elsewhere on the board
CPU_A6: U6.4 (D2); also elsewhere on the board
CPU_A7: U6.5 (D3); also elsewhere on the board
CPU_A8: U6.6 (D4); also elsewhere on the board
CPU_A9: U6.7 (D5); also elsewhere on the board
CPU_A10: U6.8 (D6); also elsewhere on the board
CPU_A11: U6.9 (D7); also elsewhere on the board
CPU_~R~W: U1.4; also elsewhere on the board
GND: C1.2, C12.2, C13.2, C14.2, C15.2, C16.2, C17.2, C18.2, U1.7 (GND), U3.6 (Inh), U3.7 (VEE), U3.8 (VSS), U6.10 (GND), U11.10 (GND), U12.3 (GND), U13.8 (GND), U14.2, U14.7 (GND), U14.12, U15.10 (GND), U16.24 (GND), U17.8 (GND); also elsewhere on the board
M2: U1.5; also elsewhere on the board
MIR_MODE: U3.10 (B); also elsewhere on the board
MIR_TYPE: U3.2 (Y0), U3.11 (A); also elsewhere on the board
NTRAM_A10: U3.3 (Z0), U3.15 (Y); also elsewhere on the board
unnamed: U1.6, U6.11 (Cp)
unnamed: U1.11, U15.1 (EO)
unnamed: U1.13, U12.4 (Q)
unnamed: U3.1 (Y1), U3.14 (X)
unnamed: U6.12 (Q7), U11.11 (B7), U15.13 (D4), U16.29 (D7)
unnamed: U6.13 (Q6), U11.12 (B6), U15.14 (D5), U16.28 (D6)
unnamed: U6.14 (Q5), U11.13 (B5), U15.17 (D6), U16.27 (D5)
unnamed: U6.15 (Q4), U11.14 (B4), U15.18 (D7), U16.26 (D4)
unnamed: U6.16 (Q3), U11.15 (B3), U15.3 (D0), U16.25 (D3)
unnamed: U6.17 (Q2), U11.16 (B2), U15.4 (D1), U16.23 (D2)
unnamed: U6.18 (Q1), U11.17 (B1), U15.7 (D2), U16.22 (D1)
unnamed: U6.19 (Q0), U11.18 (B0), U15.8 (D3), U16.21 (D0)
unnamed: U13.2 (I0a), U15.9 (Q3)
unnamed: U13.4 (Za), U16.12 (A12)
unnamed: U13.5 (I0b), U15.6 (Q2)
unnamed: U13.7 (Zb), U16.11 (A14)
unnamed: U13.9 (Zd), U16.10 (A16)
unnamed: U13.11 (I0d), U15.5 (Q1)
unnamed: U13.12 (Zc), U16.9 (A18)
unnamed: U13.14 (I0c), U15.2 (Q0)
unnamed: U3.9 (C), U13.15 (E), U14.10, U14.11, U17.15 (E)
unnamed: U6.1 (OE), U14.1
unnamed: U14.3, U14.4
unnamed: U15.15 (Q5), U17.11 (I0d)
unnamed: U15.16 (Q6), U17.2 (I0a)
unnamed: U15.19 (Q7), U17.5 (I0b)
unnamed: U16.1 (A11), U17.7 (Zb)
unnamed: U16.2 (A9), U17.4 (Za)
unnamed: U16.3 (A8), U17.9 (Zd)
unnamed: U16.4 (A13), U17.12 (Zc)
OBJ_A12: U13.3 (I1a); also elsewhere on the board
OBJ_A13: U13.6 (I1b); also elsewhere on the board
OBJ_A14: U13.10 (I1d); also elsewhere on the board
OBJ_A15: U13.13 (I1c); also elsewhere on the board
OBJ_A16: U17.6 (I1b); also elsewhere on the board
OBJ_A17: U17.3 (I1a); also elsewhere on the board
OBJ_A18: U17.10 (I1d); also elsewhere on the board
PPU_A0: U16.17 (A3); also elsewhere on the board
PPU_A1: U16.18 (A2); also elsewhere on the board
PPU_A2: U16.19 (A1); also elsewhere on the board
PPU_A3: U16.20 (A0); also elsewhere on the board
PPU_A4: U16.15 (A5); also elsewhere on the board
PPU_A5: U16.13 (A7); also elsewhere on the board
PPU_A6: U16.6 (A17); also elsewhere on the board
PPU_A7: U16.7 (A15); also elsewhere on the board
PPU_A8: U16.14 (A6); also elsewhere on the board
PPU_A9: U16.16 (A4); also elsewhere on the board
PPU_A10: U3.5 (Z0), U3.12 (X0); also elsewhere on the board
PPU_A11: U3.13 (X1), U17.13 (I1c), U17.14 (I0c); also elsewhere on the board
PPU_A12: U13.1 (S), U14.8, U17.1 (S); also elsewhere on the board
PPU_A13: U1.12, U11.19 (CE); also elsewhere on the board
PPU_D0: U11.2 (A0); also elsewhere on the board
PPU_D1: U11.3 (A1); also elsewhere on the board
PPU_D2: U11.4 (A2); also elsewhere on the board
PPU_D3: U11.5 (A3); also elsewhere on the board
PPU_D4: U11.6 (A4); also elsewhere on the board
PPU_D5: U11.7 (A5); also elsewhere on the board
PPU_D6: U11.8 (A6); also elsewhere on the board
PPU_D7: U11.9 (A7); also elsewhere on the board
VCC: C1.1, C12.1, C13.1, C14.1, C15.1, C16.1, C17.1, C18.1, U1.14 (VCC), U3.16 (VDD), U6.20 (VCC), U11.20 (VCC), U12.5 (VCC), U13.16 (VCC), U14.14 (VCC), U15.20 (VCC), U16.8 (VCC), U17.16 (VCC); also elsewhere on the board
~EN: U16.30 (CE); also elsewhere on the board
~NTRAM_CS: U14.13; also elsewhere on the board
~PPU_A13: U12.1 (D), U14.6, U14.9; also elsewhere on the board
~PPU_RD: U11.1 (A->B), U12.2 (Cp), U15.11 (Cp), U16.32 (OE); also elsewhere on the board
~PPU_WR: U14.5, U16.5 (WE); also elsewhere on the board

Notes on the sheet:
BRAD TAYLOR 04/08/2023
PPU DATA PORT ENABLED IN PPU ADDR RANGE $0000-$1FFF
CPU DATA FILL PORT $2xx7 OUTPUT ENABLED WITH PPU WRITES TO RANGE $2000-$3EFF* (xx IS THE FILL VALUE) THIS MEANS GFX MEMORY BYTE FILLING IN 4 CPU CYCLES AND INCLUDES 15-BIT LO/HI HYBRID NTRAM WRITING * NOTE THE LAST 256 BYTES OF THIS BANK CAN'T BE MODIFIED USING CPU FILLING, SINCE THIS PALETTE AREA 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
NES-FASTGFX-01, PPU SECTION
NT HI ACCESS @ $2000-$2FFF ALWAYS POINTS TO THE FIRST 2 KB OF GRAPHICS RAM
15-BIT PLAYFIELD TILES ARE VISIBLE TO THE PPU @ $0000-$0FFF
NOTE THAT ~EN MAY BE DISABLED DURING NT LO FILLS FOR JUST THE NES INTERNAL 2K NTRAM.
THIS CIRCUIT DETECTS NTRAM TILE INDEX FETCH CYCLES
WHY

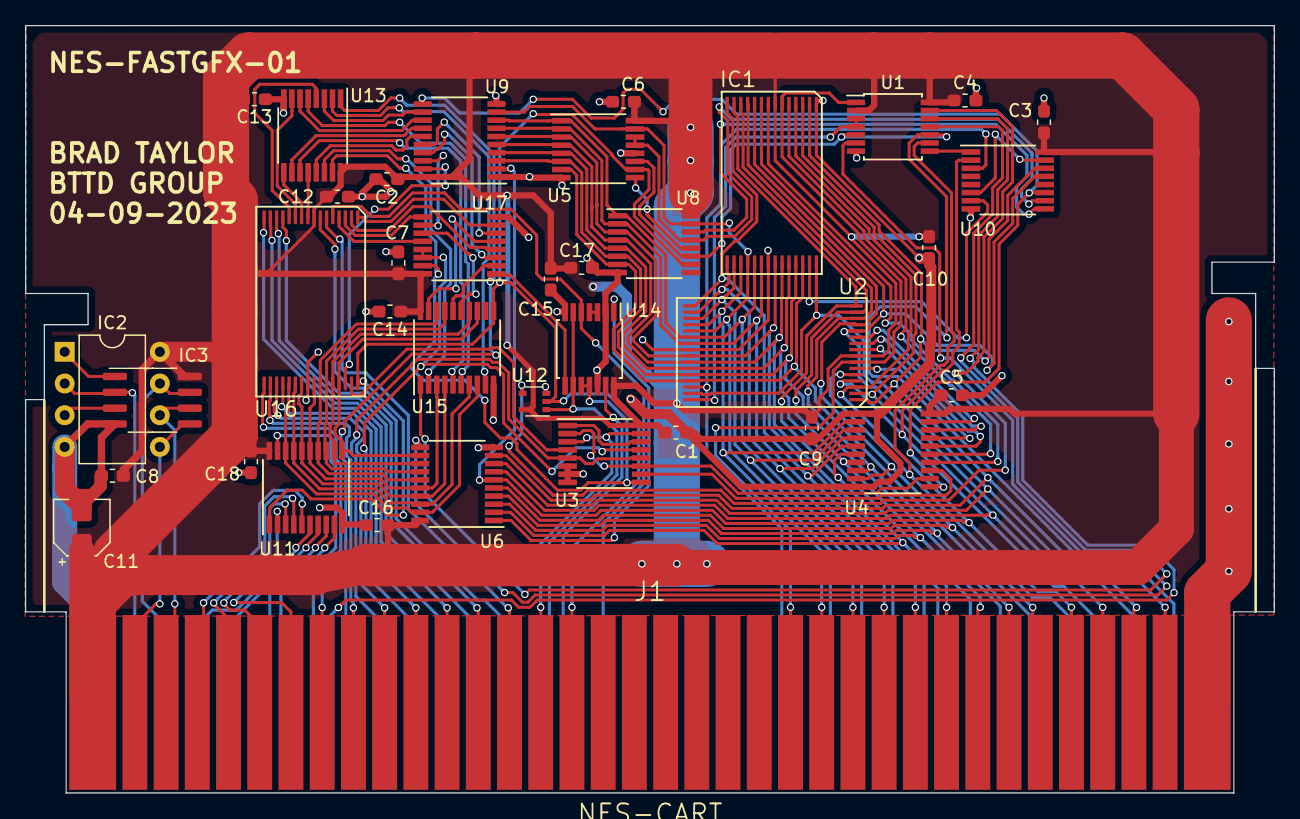
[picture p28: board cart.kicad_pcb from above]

Board: 2 copper layers, 100.0 x 61.4 mm, 38 parts (0 on the bottom side), 116 nets.

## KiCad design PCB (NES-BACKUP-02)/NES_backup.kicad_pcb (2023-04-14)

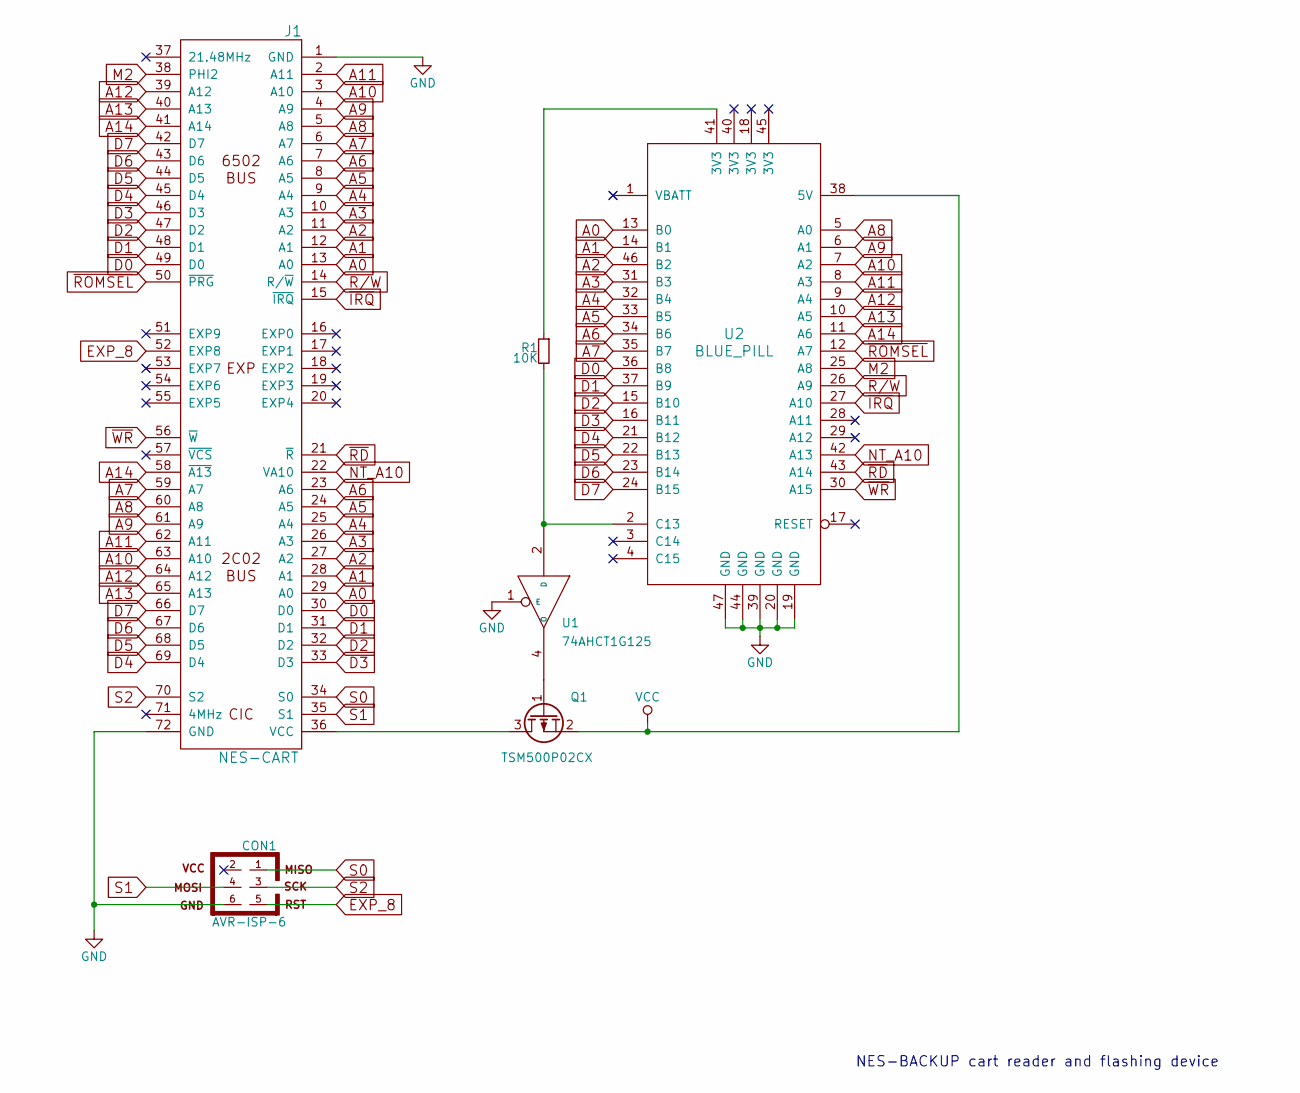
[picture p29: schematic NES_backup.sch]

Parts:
CON1: AVR-ISP-6; Pin_Header_Straight_2x03_Pitch2.54mm
J1: NES-CART; NES_CART
Q1: TSM500P02CX; SOT-23
R1: 10K; R_0402
U1: 74AHCT1G125; SOT-353_SC-70-5
U2: BLUE_PILL; blue_pill

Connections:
A0: J1.13 (A0), J1.29 (A0), U2.13 (B0)
A1: J1.12 (A1), J1.28 (A1), U2.14 (B1)
A2: J1.11 (A2), J1.27 (A2), U2.46 (B2)
A3: J1.10 (A3), J1.26 (A3), U2.31 (B3)
A4: J1.9 (A4), J1.25 (A4), U2.32 (B4)
A5: J1.8 (A5), J1.24 (A5), U2.33 (B5)
A6: J1.7 (A6), J1.23 (A6), U2.34 (B6)
A7: J1.6 (A7), J1.59 (A7), U2.35 (B7)
A8: J1.5 (A8), J1.60 (A8), U2.5 (A0)
A9: J1.4 (A9), J1.61 (A9), U2.6 (A1)
A10: J1.3 (A10), J1.63 (A10), U2.7 (A2)
A11: J1.2 (A11), J1.62 (A11), U2.8 (A3)
A12: J1.39 (A12), J1.64 (A12), U2.9 (A4)
A13: J1.40 (A13), J1.65 (A13), U2.10 (A5)
A14: J1.41 (A14), J1.58 (~A13), U2.11 (A6)
D0: J1.30 (D0), J1.49 (D0), U2.36 (B8)
D1: J1.31 (D1), J1.48 (D1), U2.37 (B9)
D2: J1.32 (D2), J1.47 (D2), U2.15 (B10)
D3: J1.33 (D3), J1.46 (D3), U2.16 (B11)
D4: J1.45 (D4), J1.69 (D4), U2.21 (B12)
D5: J1.44 (D5), J1.68 (D5), U2.22 (B13)
D6: J1.43 (D6), J1.67 (D6), U2.23 (B14)
D7: J1.42 (D7), J1.66 (D7), U2.24 (B15)
EXP_8: CON1.5, J1.52 (EXP8)
GND: CON1.6, J1.1 (GND), J1.72 (GND), U1.1 (E), U1.3 (GND), U2.19 (GND), U2.20 (GND), U2.39 (GND), U2.44 (GND), U2.47 (GND)
M2: J1.38 (PHI2), U2.25 (A8)
NT_A10: J1.22 (VA10), U2.42 (A13)
unnamed: J1.36 (VCC), Q1.3 (D)
unnamed: Q1.1 (G), U1.4 (O)
unnamed: R1.1, U2.41 (3V3)
unnamed: R1.2, U1.2 (D), U2.2 (C13)
R/W: J1.14 (R/~W), U2.26 (A9)
S0: CON1.1, J1.34 (S0)
S1: CON1.4, J1.35 (S1)
S2: CON1.3, J1.70 (S2)
VCC: Q1.2 (S), U1.5 (VCC), U2.38 (5V)
~IRQ: J1.15 (~IRQ), U2.27 (A10)
~RD: J1.21 (~R), U2.43 (A14)
~ROMSEL: J1.50 (~PRG), U2.12 (A7)
~WR: J1.56 (~W), U2.30 (A15)

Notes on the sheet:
NES-BACKUP cart reader and flashing device

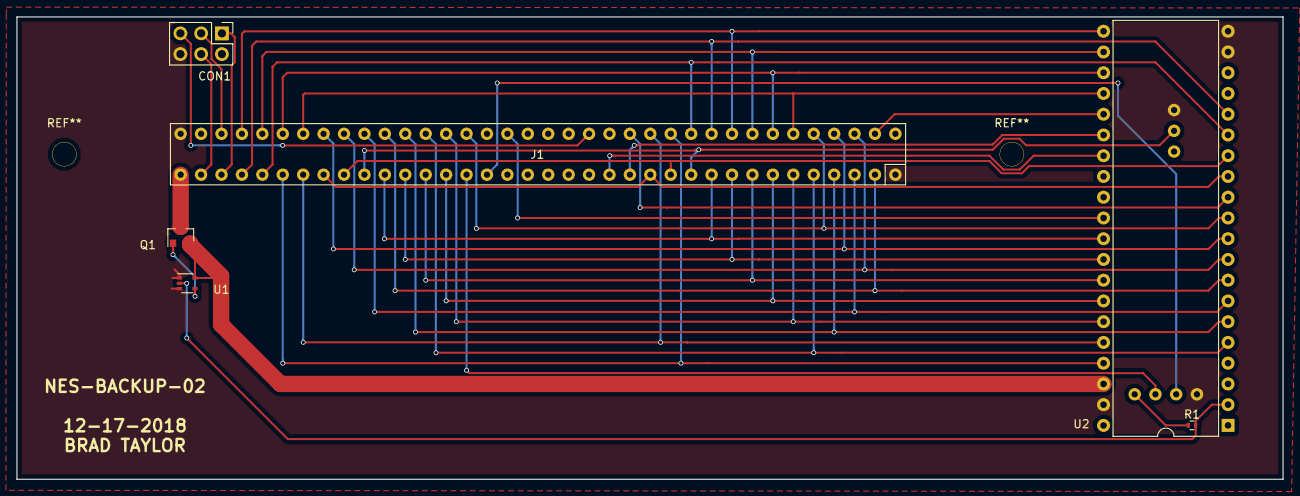
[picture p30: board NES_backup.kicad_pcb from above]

Board: 2 copper layers, 155.0 x 56.6 mm, 6 parts (0 on the bottom side), 40 nets.

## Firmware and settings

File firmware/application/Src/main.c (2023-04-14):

// USB-NES Lite 0.79 FIRM-proof (TM) application
// Copyright 2019 Big Time Technology Development Group.

/* Includes */
#include <string.h>
#include "stm32f1xx_hal.h"

#define						DIRTY_TIMEOUT				1000
#define						MSEC_const					(72000000 / 1000)
#define						SAVE_SIZE					1024
#define						BCMTABLE_SIZE				1024
#define						OVERRIDE_SIZE				4096
#define						RAM_BASE					0x20002800U
#define						RAM_USED					4608
#define						BOOT_BLOCK_BASE				0x08000000U
#define						APPLICATION_BASE			0x08008000U
#define						SETTINGS_BASE				0x0800E800U
#define						BCMTABLE_BASE				0x0800EC00U
#define						OVERRIDE_BASE				0x0800F000U
#define						DEMO_BASE					0x08010000U
#define						BOOT_BLOCK					((t_boot_block *) BOOT_BLOCK_BASE )
#define						APPLICATION					((t_app_header *) APPLICATION_BASE)
#define						DEMO_NES					((t_demo	   *) DEMO_BASE		  )
#define						SETTINGS_BIN				((t_settings   *) SETTINGS_BASE	  )
#define						OVERRIDE_BIN				((t_override   *) OVERRIDE_BASE	  )
#define						BCMTABLE_BIN				((t_bcmtable   *) BCMTABLE_BASE	  )
#define						simple_types				BCMTABLE_BIN
#define						SETTINGS_ITEMS				(sizeof (t_settings_int) / sizeof (short))

typedef	union {

	unsigned char			byte						[2][16];
	short					half						[16];

} t_bcmtable;

typedef union {

	char					byte						[SAVE_SIZE  ];
	uint16_t				half						[SAVE_SIZE/2];

} t_settings;

typedef union {

	unsigned char *			byte;
	unsigned short *		half;
	unsigned int *			word;

} ptr_all_types;

typedef struct {

	uint8_t					company_name				[ 8];
	uint8_t					product_name				[16];
	uint8_t					version						[ 4];

} t_product;

typedef struct {

	uint8_t					filename					[11];
	uint8_t					attributes;
	uint8_t					lowercase_letters;			//	bit 3 for lowercase filename; bit 4 for lowercase extension
	uint8_t					creation_time_cs;
	uint16_t				creation_time;
	uint16_t				creation_date;
	uint16_t				last_access_date;
	uint16_t				starting_cluster_hi;
	uint16_t				modification_time;
	uint16_t				modification_date;
	uint16_t				starting_cluster;
	uint32_t				file_size;

} t_dir_slot;

typedef struct {

	uint8_t					stuff						[0x09AC];
	void					(* unlock_fpec				) (void);
	uint32_t				(* decrypt					) (uint32_t * buf, uint32_t * flash_addr);
	void					(* page_erase_handler		) (uint32_t reg_base, t_settings * dest);
	void					(* flash_halfword_handler	) (uint32_t reg_base, t_settings * dest, uint32_t data);
	void					(* flash_kernel_handler		) (uint32_t retry_count);
	t_dir_slot				firmware_dir_entry;
	t_dir_slot				security_dir_entry;
	uint8_t					boot_sector					[512];
	t_product				product_ID;
	uint8_t					hardware_ID					[ 12];
	uint8_t					authentication_block		[728];
	uint32_t				encryption_key				[ 64];

} t_boot_block;

typedef struct {

	uint32_t				file_size;					//	in 32-bit words
	uint32_t				CRC32;
	t_product				product;

} t_app_header;

typedef void				(* ptr_io_handler			) (ptr_all_types buf, uint32_t file_ofs);	// file offset in sectors

typedef struct {

	t_dir_slot				dir_entry;
	ptr_io_handler			read_handler;
	ptr_io_handler			write_handler;

} t_file;

typedef t_file				(* ptr_file					);
typedef	t_dir_slot			(* ptr_dir_slot				);
typedef uint8_t				t_demo						[65536];

typedef struct {

	ptr_dir_slot			(* create_file_handler		) (ptr_file	ptr);
	ptr_dir_slot			(* make_file_handler		) (char * filename, uint32_t filesize, ptr_io_handler rd_hndlr, ptr_io_handler wr_hndlr);
	void					(* delete_file_handler		) (ptr_dir_slot	ptr);
	void					(* media_change_handler		) (void);

} t_kernel_functions;

extern void					init						(t_kernel_functions * ptr);
extern void					systick						(void);

//---------------------------------------------------------------------------------------------------------
//timing stuff for cart io access

typedef struct {

	unsigned short			wait;
	unsigned short			max_wait;
	char *					name;

} t_wait_item;

typedef struct {

	unsigned short			unit_power_warmup;
	unsigned short			idle_powerdown_ms;
	unsigned short			battery_power_down;
	unsigned short			quick_discharge_enable;
	unsigned short			battery_test_enable;
	unsigned short			bus_disable;
//	unsigned short			MMC3_emulation_on;

	unsigned short			ASIC_map_testing_on;
	unsigned short			alt_bus_con_test_on;
	unsigned short			conflict_testing_on;
	unsigned short			_16KB_PRG_ROM_test;
	unsigned short			override_testing_on;
	unsigned short			override_mode_index;
	unsigned short			NES_2_0_enable;

	unsigned short			README_TXT_enable;
	unsigned short			REPORT_TXT_enable;
	unsigned short			RESETNES_TXT_on;
	unsigned short			OVERRIDE_TXT_on;
	unsigned short			OVERRIDE_BIN_on;
	unsigned short			BCMTABLE_BIN_on;
	unsigned short			debug_enable;
	unsigned short			DEMO_NES_enable;

} t_settings_int;

const t_wait_item			ch_init						[SETTINGS_ITEMS] = {

	{	100,	 1000,		"powerup_warmup_ms"			},
	{	500,	 1000,		"idle_powerdown_ms"			},
	{  1000,	10000,		"batt_powerdown_ms"			},
	{	  0,		1,		"PD_discharge_enable"		},
	{	  1,		1,		"battery_test_enable"		},
	{	  0,		1,		"ROM.W_bus_disable"			},
//	{	  1,		1,		"map_268_MMC3_mode"			},

	{	  1,		1,		"ASIC_map_testing_on"		},
	{	  1,		1,		"alt_buscon_tests_on"		},
	{	  1,		1,		"conflict_testing_on"		},
	{	  1,		1,		"16_KB_PRG-ROM_test"		},
	{	  1,		1,		"override_testing_on"		},
	{	  0,	  128,		"default_map_index"			},
	{	  0,	  	9,		"NES_2.0___enable"			},

	{	  1,		1,		"README.TXT_enable"			},
	{	  0,		1,		"REPORT.TXT_enable"			},
	{	  1,		1,		"DETECT.TXT_enable"			},
	{	  1,		1,		"OVERRIDE.TXT_enable"		},
	{	  0,		1,		"OVERRIDE.BIN_enable"		},
	{	  1,		1,		"BCMTABLE.BIN_enable"		},
	{	  0,		1,		"BCMTABLE_reporting"		},
	{	  0,		1,		"DEMO.NES__enable"			},

};

const char					readme_txt					[] = {
							"Visit usbnes.com for the latest info, updates, user's guide, legal and more."
//							"\r\n\r\nUSB-NES (TM)"
//							"\r\nCopyright (C) 2019 Big Time Technology Development Group."
//							"\r\nAll rights reserved."
};

union {

	unsigned short			item						[SETTINGS_ITEMS];
	t_settings_int			items;

} ch;

unsigned char *				fpos;
t_kernel_functions *		ptr_krnl;

typedef struct {

	// iNES header
	unsigned int		iNES_signature;
	unsigned char		PRG_ROM_size;
	unsigned char		CHR_ROM_size;
	unsigned char		flags_6;
	unsigned char		flags_7;
	unsigned char		submapper;
	unsigned char		PRG_CHR_ROM_size_MSB;
	unsigned char		PRG_RAM_size;
	unsigned char		CHR_RAM_size;
	unsigned char		stuff [4];

	// override header
	unsigned short		PRG_bank_ofs;
	unsigned short		CHR_bank_ofs;
	unsigned short		PRG_bank_ofs_SRAM;
	unsigned short		CHR_bank_ofs_SRAM;
	unsigned char		PRG_bank_bits;					//	size of bank in bit count
	unsigned char		CHR_bank_bits;
	unsigned char		PRG_bank_bits_SRAM;
	unsigned char		CHR_bank_bits_SRAM;
	unsigned char		SEQ_present;					//	bits 0, 1: INIT & DOWN sequence following any PRG, CHR, SAV section
	unsigned char		mode;							//	bit 7: MMC1 mode (serialize 5 bits, ctrl_reg = 01100b)
	unsigned short		CRLF;

} t_h_override;

typedef struct {

	unsigned char		address_map			[16];
	unsigned char		data_dir;
	unsigned char		data_map			[ 8];
	unsigned char		SP2;
	unsigned char		ID_string			[ 4];
	unsigned short		CRLF;

} t_s_override;

typedef struct {

	unsigned char		text				[16];
	unsigned char		reserved			[12];
	unsigned int		signature;

} t_n_override;

typedef union {

	t_h_override		header				[OVERRIDE_SIZE / 32];
	t_s_override		sequence			[OVERRIDE_SIZE / 32];
	t_n_override		name				[OVERRIDE_SIZE / 32];
	t_bcmtable			data				[OVERRIDE_SIZE / 32];
	unsigned short		half				[OVERRIDE_SIZE /  2];
	unsigned char		byte				[OVERRIDE_SIZE	   ];

} t_override;

union {

	unsigned char		buf					[1024];
	unsigned short		Buf					[512];

} debug;

//---------------------------------------------------------------------------------------------------------
// these functions maintain the settings.txt file and the timing parameters

int next_delimiter () {

	// loop to find delimiters
	int i = SAVE_SIZE;
	do {
		fpos++;
		switch (fpos [0]) {

		case   0:
		case 255:	return -1;
		case   9:
		case  10:
		case  13:
		case  32:	return  0;

		}
	} while (--i);
	return -1;
}

int next_string () {

	// loop while in delimiters
	int i = SAVE_SIZE;
	do {
		fpos++;
		switch (fpos [0]) {

		default :	return  0;
		case   0:
		case 255:	return -1;
		case   9:
		case  10:
		case  13:
		case  32:;

		}
	} while (--i);
	return -1;
}

int next_number (uint32_t * num) {

	// find size of number string
	unsigned char * endpos = fpos;
	next_delimiter ();
	if ((int) fpos - (int) endpos > 10) return -1;

	// extract the digits
	unsigned char * curpos = fpos;
	unsigned int i = 1;
	num [0] = 0;
	do {

		curpos--;
		char tmp = curpos [0];
		switch (tmp) {

			default				: return -1;
			case '0' ... '9'	: num [0] += (tmp - '0') * i;

		}
		i *= 10;

	} while (curpos != endpos);
	return 0;
}

// will import all existing settings from file
uint8_t settings_items;
void import_settings (register t_settings * buf, int init_) {

	// find the new settings
	int ctr = 0;
	buf -> byte [SAVE_SIZE - 1] = 0;					//	inject a null char in there to terminate strstr ()
	for (register uint32_t j = 0; j < settings_items; j++) {

		// find the string
		fpos = (unsigned char *) strstr ((char *) buf, ch_init [j].name);
		if (!fpos)										goto FAIL;

		// advance past the name string
		if (next_delimiter ())							goto FAIL;
		if (next_string	   ())							goto FAIL;

		// check next param for '='
		unsigned char * oldpos = fpos;
		if (next_delimiter ())							goto FAIL;
		if ( 1  != (int) fpos - (int) oldpos	)		goto FAIL;
		if ('=' !=					  oldpos [0])		goto FAIL;

		// advance to number
		if (next_string	())								goto FAIL;

		// get the number
		uint32_t tmp_u;
		if (next_number (&tmp_u))						goto FAIL;

		// test against maximum parameter
		if (tmp_u > ch_init [j].max_wait)				goto FAIL;

		// assign the setting
		ch.item [j] = tmp_u;
		ctr++;
		continue;

		// load the default setting if no new one found
FAIL:	ch.item [j] = ch_init [j].wait;
	}

	// import parameters from new data, check to see if all parameters are present
	if (ctr != settings_items) {

		// rewrite settings file if not all parameters there
		register int pos = 0;
		for (register uint32_t j = 0; j < settings_items; j++)

			// write each setting parameter out to the buffer line by line
			pos += sprintf (& buf -> byte [pos], "%s\t=\t%u\r\n", ch_init [j].name, ch.item [j]);

	// don't update flash if running from init
	} else if (init_) return;

	// unlock FPEC
	BOOT_BLOCK -> unlock_fpec ();

  	// erase existing block
	BOOT_BLOCK -> page_erase_handler (0x40022000, SETTINGS_BIN);	// erase last 1KB of 64KB segment

	// copy new data into flash
	for (register uint32_t j = 0; j < (SAVE_SIZE / 2); j++)

		BOOT_BLOCK -> flash_halfword_handler (0x40022000, (t_settings *) & SETTINGS_BIN -> half [j], buf -> half [j]);

}

//---------------------------------------------------------------------------------------------------------
/*
const t_bcmtable simple_types [] = {
//const unsigned char simple_types [][2][16] = {
	{{ 	  3, 0x1C, 0x00,		0x00,		0x00, 0x00, 0x00, 0x00,		0x7F, 0x7F, 0x7F, 0x7F, 0x7F, 0x7F, 0x7F, 0x7F }, "CNROM           " },
	{{ 	 66, 0x1C, 0x00,		0x00,		0xF0, 0xF0, 0xF0, 0xF0,		0x0F, 0x0F, 0x0F, 0x0F, 0x0F, 0x0F, 0x0F, 0x0F }, "GNROM           " },
	{{ 	  7, 0x0C, 0x00,		0x10,		0x0F, 0x0F, 0x0F, 0x0F,		0x00, 0x00, 0x00, 0x00, 0x00, 0x00, 0x00, 0x00 }, "AOROM           " },
	{{ 	 34, 0x0C, 0x00,		0x00,		0x3F, 0x3F, 0x3F, 0x3F,		0x00, 0x00, 0x00, 0x00, 0x00, 0x00, 0x00, 0x00 }, "BNROM           " },
	{{ 	  2, 0x04, 0x00,		0x00,		0x0F, 0x0F, 0x00, 0x00,		0x00, 0x00, 0x00, 0x00, 0x00, 0x00, 0x00, 0x00 }, "UNROM           " },
	{{ 	180, 0x06, 0x00,		0x00,		0x00, 0x00, 0x7F, 0x7F,		0x00, 0x00, 0x00, 0x00, 0x00, 0x00, 0x00, 0x00 }, "UNROM + HC08    " },
	{{ 	152, 0x14, 0x00,		0x80,		0x70, 0x70, 0x00, 0x00,		0x0F, 0x0F, 0x0F, 0x0F, 0x0F, 0x0F, 0x0F, 0x0F }, "Arkanoid 2      " },
	{{ 	 78, 0x14, 0x00,		0x08,		0x07, 0x07, 0x00, 0x00,		0xF0, 0xF0, 0xF0, 0xF0, 0xF0, 0xF0, 0xF0, 0xF0 }, "Holy Diver      " },
	{{ 	 11, 0x1C, 0x00,		0x00,		0x03, 0x03, 0x03, 0x03,		0xF0, 0xF0, 0xF0, 0xF0, 0xF0, 0xF0, 0xF0, 0xF0 }, "Color Dreams    " },
	{{ 	148, 0x1C, 0x00,		0x00,		0x08, 0x08, 0x08, 0x08,		0x07, 0x07, 0x07, 0x07, 0x07, 0x07, 0x07, 0x07 }, "Tengen 800008   " },
	{{ 	149, 0x1C, 0x00,		0x00,		0x00, 0x00, 0x00, 0x00,		0x80, 0x80, 0x80, 0x80, 0x80, 0x80, 0x80, 0x80 }, "Mahjong 16      " },
	{{ 	 77, 0x4C, 0x00,		0x00,		0x0F, 0x0F, 0x0F, 0x0F,		0xF0, 0xF0, 0x00, 0x00, 0x00, 0x00, 0x00, 0x00 }, "Napoleon Senki  " },
	{{ 	 89, 0x14, 0x00,		0x08,		0x70, 0x70, 0x00, 0x00,		0x87, 0x87, 0x87, 0x87, 0x87, 0x87, 0x87, 0x87 }, "Mito Koumon     " },
	{{ 	 93, 0x04, 0x01,		0x00,		0xF0, 0xF0, 0x00, 0x00,		0x00, 0x00, 0x00, 0x00, 0x00, 0x00, 0x00, 0x00 }, "Fantasy Zone    " },
	{{ 	107, 0x1C, 0x00,		0x00,		0x3E, 0x3E, 0x3E, 0x3E,		0x3F, 0x3F, 0x3F, 0x3F, 0x3F, 0x3F, 0x3F, 0x3F }, "Magic Dragon    " },
	{{ 	 29, 0x04, 0x00,		0x00,		0x1C, 0x1C, 0x00, 0x00,		0x03, 0x03, 0x03, 0x03, 0x03, 0x03, 0x03, 0x03 }, "Sealie Computing" },
	{{ 	 96, 0x0C, 0x00,		0x00,		0x03, 0x03, 0x03, 0x03,		0x04, 0x04, 0x04, 0x04, 0x04, 0x04, 0x04, 0x04 }, "Oeka Kids       " },
	{{ 	188, 0x04, 0x00,		0x20,		0x0F, 0x0F, 0x00, 0x00,		0x00, 0x00, 0x00, 0x00, 0x00, 0x00, 0x00, 0x00 }, "Karaoke Studio  " },
	{{ 	 13, 0x3C, 0x00,		0x00,		0x00, 0x00, 0x00, 0x00,		0x00, 0x00, 0x00, 0x00, 0x03, 0x03, 0x03, 0x03 }, "CPROM           " },
	{{ 	 30, 0x04, 0x00,		0x00,		0x1F, 0x1F, 0x00, 0x00,		0x00, 0x00, 0x00, 0x00, 0x00, 0x00, 0x00, 0x00 }, "UNROM-512  8K   " },
	{{ 	 30, 0x04, 0x00,		0x80,		0x1F, 0x1F, 0x00, 0x00,		0x00, 0x00, 0x00, 0x00, 0x00, 0x00, 0x00, 0x00 }, "UNROM-512  8K MM" },
	{{ 	 30, 0x04, 0x00,		0x00,		0x1F, 0x1F, 0x00, 0x00,		0x60, 0x60, 0x60, 0x60, 0x60, 0x60, 0x60, 0x60 }, "UNROM-512 32K   " },
	{{ 	 30, 0x04, 0x00,		0x80,		0x1F, 0x1F, 0x00, 0x00,		0x60, 0x60, 0x60, 0x60, 0x60, 0x60, 0x60, 0x60 }, "UNROM-512 32K MM" },
	{{ 	 94, 0x04, 0x00,		0x00,		0x1C, 0x1C, 0x00, 0x00,		0x00, 0x00, 0x00, 0x00, 0x00, 0x00, 0x00, 0x00 }, "UN1ROM          " },
	{{ 	 70, 0x14, 0x00,		0x00,		0xF0, 0xF0, 0x00, 0x00,		0x0F, 0x0F, 0x0F, 0x0F, 0x0F, 0x0F, 0x0F, 0x0F }, "Family Trainer  " }
};
*/
//#define			simple_cnt (sizeof (simple_types) / 32)
/*
union {

		unsigned char	byte	[8];
		unsigned short	hword	[4];
		unsigned int	word	[2];

} error_info [BCMTABLE_SIZE / 32];
*/
//---------------------------------------------------------------------------------------------------------

#define			CHR_KEYS			16
const uint16_t	CHR_keys [4][CHR_KEYS] = {
	{ 0x0010, 0x014A, 0x0001, 0x024D, 0x03D0, 0x0040, 0x0076, 0x0238, 0x02B1, 0x0360, 0x03FF,      0,      0,      0,      0,      0 },		//	1K
	{ 0x0232, 0x0014, 0x03DA, 0x0541, 0x0001, 0x07D0, 0x0040, 0x00E0, 0x0238, 0x0240, 0x02B1, 0x0330, 0x0474, 0x0760, 0x07FF,      0 },		//	2K
	{ 0x0412, 0x0014, 0x01CB, 0x0001, 0x0A50, 0x0E2D, 0x0040, 0x0760, 0x0FD0, 0x0238, 0x0330, 0x0474, 0x0AB1, 0x0FFF,      0,      0 },		//	4K
	{ 0x1C46, 0x131B, 0x0430, 0x1B42, 0x0000, 0x0040, 0x0238, 0x0760, 0x0800, 0x1AB1, 0x1D00, 0x1FC7, 0x1FFF,      0,      0,      0 }};	//	8K

#define			PRG_KEYS			 8
const uint16_t  PRG_keys [3][PRG_KEYS] = {
	{ 0x1FFD, 0x0100, 0x0040, 0x0025, 0x10C1, 0x1400, 0x1FA5, 0x1FC8 },		//	 8K
	{ 0x0105, 0x2040, 0x3FFB, 0x0025, 0x10C1, 0x3400, 0x3FA5, 0x3FC8 },		//	16K
	{ 0x1040, 0x4025, 0x7400, 0x10C1,      0,      0,      0,      0 }};	//	32K

#define ROMSEL					0x0080
#define M2						0x0100
#define CPU_RW					0x0200
#define CART_POWER				0x2000
#define NT_A10					0x2000
#define PPU_RD					0x4000
#define PPU_WR					0x8000
#define b31						0x80000000

typedef void	(*cart_io) (uint8_t *buf, uint32_t ROM_addr);
typedef void	(*bank_sw) (uint32_t addr);
typedef void	(*save_en) (void);

//typedef int		(*mirr_sw) (uint32_t d);
typedef union {

		void	(*mirr) (uint32_t d);
		int		(*test) (uint32_t d);

} mirr_sw;

static void scan_PRG	(void);
static void NUL_xxx		(void		) {	  };
static void NUL_xXx		(uint32_t b	) {	  };
static int  goto_bank	(uint32_t b		  );
static void PRG_xxx		(uint32_t ROM_addr);
static void CHR_xxx		(uint32_t ROM_addr);
static void null_io		(register ptr_all_types buf, register uint32_t file_ofs) {}



typedef struct { uint8_t data [26]; uint16_t first_cluster; uint32_t size; } DIRinfo;
typedef struct {
	uint8_t		map_no;			//	iNES mapper #
	uint8_t		init;			//	contains an init value, usually a bank shift value (or SRAM enable for MMC3/MMC6)
	uint16_t	SAV_base;		//	used to detect SRAM when smaller than 8K
	uint8_t		SAV_msb;		//	bit offset to start SRAM size test at
	uint8_t		PRG_msb;		//	bit offset to start PRG  size test at
	uint8_t		PRG_bank_size;	//	in bits from the LSB
	uint8_t		PRG_ofs;		//	offset value in bank size units
	uint8_t		CHR_msb;
	uint8_t		CHR_bank_size;
	uint8_t		CHR_ofs;
	uint8_t		reserved_1;
	uint32_t	reserved_2;
	uint32_t	reserved_3;
	save_en		INIT_;			//	sets the banking modes & enables SRAM
	save_en		DOWN_;			//	disables the SRAM
	mirr_sw		MIR_;			//	mirroring control abstract used to identify most ASIC types
	bank_sw		SAV_B;			//	save RAM banking abstraction
	bank_sw		PRG_B;			//	PRG ROM banking abstraction
	bank_sw		CHR_B;			//	CHR ROM banking abstraction
	save_en		TEST_;			//	mapper-specific tests (i.e., IRQ, 4-screen NTRAM, etc.)
	char		text [16];		//	mapper type designation
} MAPinfo;

// define the output parameters from autodetection
typedef struct {

	unsigned int	PRG_ROM_size;
	unsigned int	PRG_bank_mask;
	unsigned short	PRG_mask;
	unsigned char	PRG_B_mask;
	unsigned char	reserved_1;

	unsigned int	CHR_ROM_size;
	unsigned int	CHR_bank_mask;
	unsigned short	CHR_mask;
	unsigned char	CHR_B_mask;
	unsigned char	reserved_2;

	unsigned int	SRAM_size;
	unsigned int	SAV_bank_mask;
	unsigned short	SAV_mask;
	unsigned char	SAV_B_mask;
	unsigned char	SAV_B_ofs;

	unsigned short	SAV_ofs;
	unsigned short	base;		//	register base for mapper 268

//	unsigned short	PRG_ofs;
//	unsigned char	PRG_B_ofs;
//	unsigned short	CHR_ofs;
//	unsigned char	CHR_B_ofs;

	// the index values here are always grouped as 8 in this sequence!
	unsigned char	header_override_index;
	unsigned char	PRG_override_index;
	unsigned char	CHR_override_index;
	unsigned char	SAV_override_index;
	unsigned char	INIT_override_index;
	unsigned char	DOWN_override_index;
	unsigned char	TEST_override_index;
	unsigned char	name_override_index;

	// reserved for future expansion
	unsigned char	reserved_4 [5];
	unsigned char	SRAM_err;
	unsigned char	init_mode;
	unsigned char	mode;

} t_v;
t_v v;

const uint8_t	NES_header_init [32]	= { 0x4E, 0x45, 0x53, 0x1A, 0x02, 0x01, 0x00, 0x00, 0,0,0,0,0,0,0,0,
										0, 0x80, 0, 0, 0, 0, 0, 0, 15,13, 0,0,0,0, 13, 10};

const MAPinfo	map_init			= { 0,0,	0x6000,12,	14,15,1,	12,13,0,	0,0,0,	NUL_xxx, NUL_xxx, {NUL_xXx}, NUL_xXx, PRG_xxx, CHR_xxx,  NUL_xxx,	"NROM 128/256    " };

char			report_txt	[512];
uint16_t		data_table	[256];
uint16_t		root_table	[256];
uint8_t			PRG_bank_tbl[256];
uint8_t			CHR_bank_tbl[256];
uint8_t			bank_sig	[CHR_KEYS];

union {

	uint8_t			b			[32];
	t_h_override	r;

} info;

uint8_t			score		[ 16];		// for simple_types bit-bang tests

uint8_t			PRG_erase	[128];
uint8_t			CHR_erase	[128];

MAPinfo			map;

uint32_t		files_dirty;

uint32_t		CPU_W_enable;
uint32_t		CPU_W_disable;
uint32_t		bs_helper;
uint32_t		old_PRG_bank;			// current PRG bank
uint32_t		old_CHR_bank;			// current CHR bank
uint32_t		old_SAV_bank;			// current SAV bank

uint32_t		timeout;
uint32_t		(* chr_src		)	(register uint32_t addr);
uint32_t		(* sram_src_R	)	(register uint32_t addr);
void			(* sram_src_W	)	(register uint32_t addr, register uint32_t data);

unsigned short	seq_ctr;
unsigned char *	src_pos;
unsigned char *	dest_pos;

short			settings_old_mod_time;

uint8_t			cur_bank;
uint8_t			SAV_size;				//	total amount of SRAM in 2^n, battery backed or not
uint8_t			CHR_RAM;				//	non-zero if CHR-RAM detected
uint8_t			override_erase;
uint8_t			bcmtable_erase;
uint8_t			settings_dirty;
uint8_t			pull;
uint8_t			bus_contention;
uint8_t			info_4_mask;			//	indicates validity of info [4] after call to scan PRG
uint8_t			info_5_mask;			//	indicates validity of info [5] after call to scan CHR
uint8_t			simple_cnt;

//---------------------------------------------------------------------------------------------------------
// at 72 MHz, delay provides CPU-clock accurate delays for up to a minute.
void chill (register uint32_t cycles) {

	register uint32_t i = DWT -> CYCCNT;
	while ((DWT -> CYCCNT - i) < cycles);

}

// disable any SRAM, tri-state all GPIO lines, and cut the power to the cart
static void shut_down (void) {
  	map.DOWN_ ();				// disable SRAM
	GPIOA->CRL = 0x44444444;	// disable A8-A14, ROMSEL
	GPIOB->CRL = 0x44444444;	// disable A0-A7
	GPIOB->CRH = 0x44444444;	// disable D0-D7
	GPIOA->CRH = 0x44444444;	// disable M2, R/W, PPU_RD, PPU_WR
	GPIOC->BSRR = CART_POWER;	// shut off cart power
	old_PRG_bank = 0xFFFFFFFF;
	old_CHR_bank = 0xFFFFFFFF;
	old_SAV_bank = 0xFFFFFFFF;
	timeout = 0;
}

// tries to discharge the cart by intentionally causing bus shorts
void discharge () {

	GPIOA -> ODR = 0x0000 | CPU_RW | PPU_WR;
	GPIOB -> ODR = 0x0000;
	GPIOB -> CRL = 0x33333333;				// enable A0-A7 outputs
	GPIOB -> CRH = 0x33333333;				// enable D0-D7
	GPIOA -> CRL = 0x33333333;				// enable A8-A14, ROMSEL outputs
	GPIOA -> CRH = 0x43444443;				// enable M2, PPU_RD

}

void systick (void) {

	if (timeout) {
		timeout --;
		if (! timeout)
			shut_down ();

	}
	if (files_dirty) {
		files_dirty --;
		if (! files_dirty) {

			if (settings_dirty)				import_settings ((t_settings *) debug.buf, 0);
			ptr_krnl -> media_change_handler ();

		}
	}
}
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
int main () { return 0; }

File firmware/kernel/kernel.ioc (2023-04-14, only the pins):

Mcu.UserName=STM32F103C8Tx
PA0-WKUP.Signal=GPIO_Input
PA1.Signal=GPIO_Input
PA10.Signal=GPIO_Input
PA11.Signal=USB_DM
PA12.Signal=USB_DP
PA13.Signal=GPIO_Input
PA14.Signal=GPIO_Input
PA15.Signal=GPIO_Input
PA2.Signal=GPIO_Input
PA3.Signal=GPIO_Input
PA4.Signal=GPIO_Input
PA5.Signal=GPIO_Input
PA6.Signal=GPIO_Input
PA7.Signal=GPIO_Input
PA8.Signal=GPIO_Input
PA9.Signal=GPIO_Input
PB0.Signal=GPIO_Input
PB1.Signal=GPIO_Input
PB10.Signal=GPIO_Input
PB11.Signal=GPIO_Input
PB12.Signal=GPIO_Input
PB13.Signal=GPIO_Input
PB14.Signal=GPIO_Input
PB15.Signal=GPIO_Input
PB2.Signal=GPIO_Input
PB3.Signal=GPIO_Input
PB4.Signal=GPIO_Input
PB5.Signal=GPIO_Input
PB6.Signal=GPIO_Input
PB7.Signal=GPIO_Input
PB8.Signal=GPIO_Input
PB9.Signal=GPIO_Input
PC13-TAMPER-RTC.Signal=GPIO_Output
PD0-OSC_IN.Signal=RCC_OSC_IN
PD1-OSC_OUT.Signal=RCC_OSC_OUT

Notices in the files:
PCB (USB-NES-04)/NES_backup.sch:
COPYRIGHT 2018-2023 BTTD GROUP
